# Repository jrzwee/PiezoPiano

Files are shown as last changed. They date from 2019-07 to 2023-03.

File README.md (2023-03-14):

# PiezoPiano
PiezoPiano is a PCB piano which can play one octave - all at once. It is programmed via Arduino. It is available for purchase in my [Tindie Store](https://www.tindie.com/products/zaan/piezo-piano/). 

If you like this project, feel free to support me 😇

 

<a href="https://www.buymeacoffee.com/zaan" target="_blank">Buy Me A Coffee</a>

<p align="center">
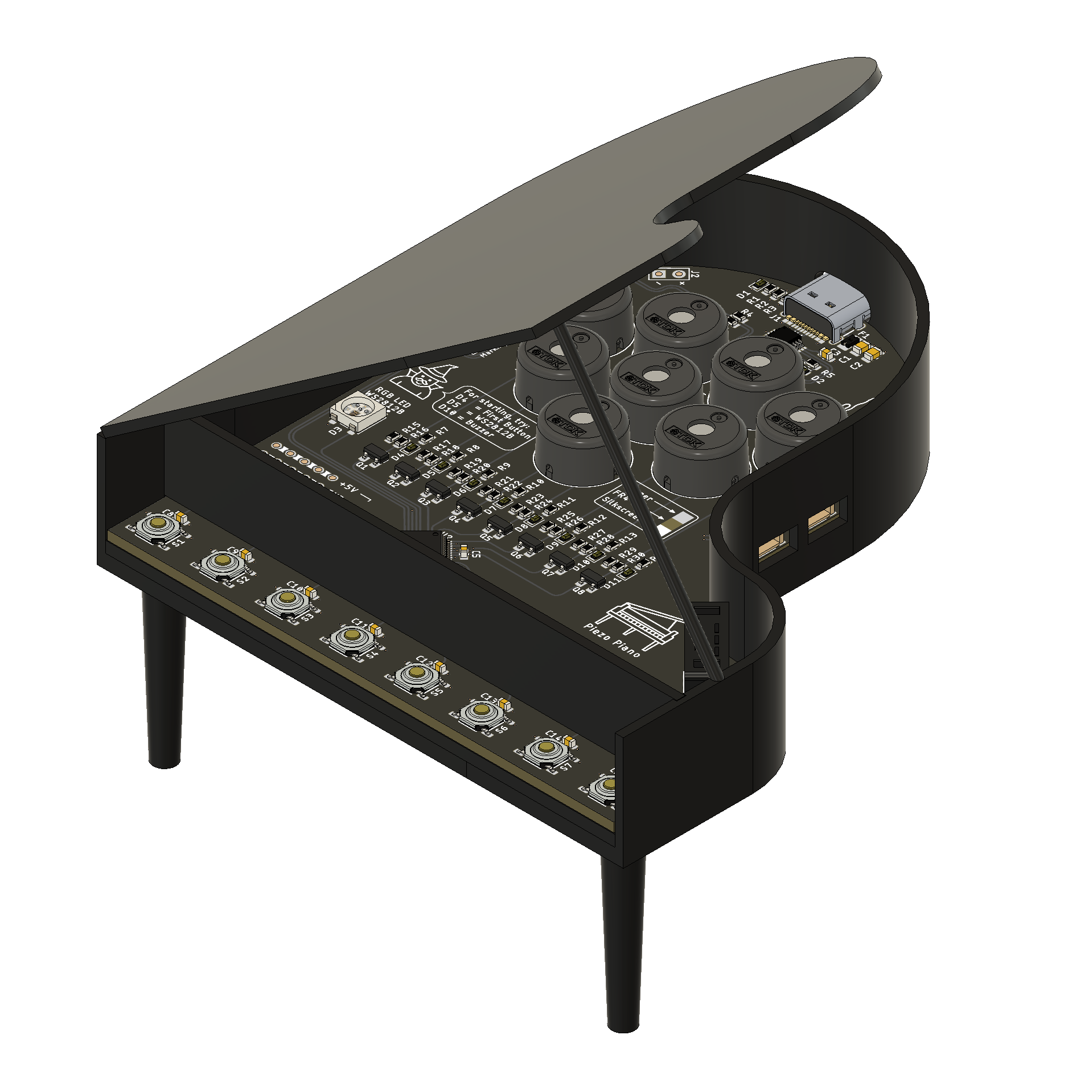
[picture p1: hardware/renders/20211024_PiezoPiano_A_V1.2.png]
  
</p>

## Setup for the Arduino IDE
This project is based on the great work of Hans with his [MegaCoreX](https://github.com/MCUdude/MegaCoreX). Visit this repo for further install instructions.
Select following settings in the Arduino IDE:

✅ **Board**: ATmega4809 \
✅ **COM Port**: Select the one your PiezoPiano is connected to \
✅ **Bootloader**: Optiboot (UART1 default pins) \
✅ **Pinout**: 48 pin standard

## Pinout
PCB Pinout

## Build of Material - BOM
TBD as there is a refactoring in the making.

## Renders
<p align="center">
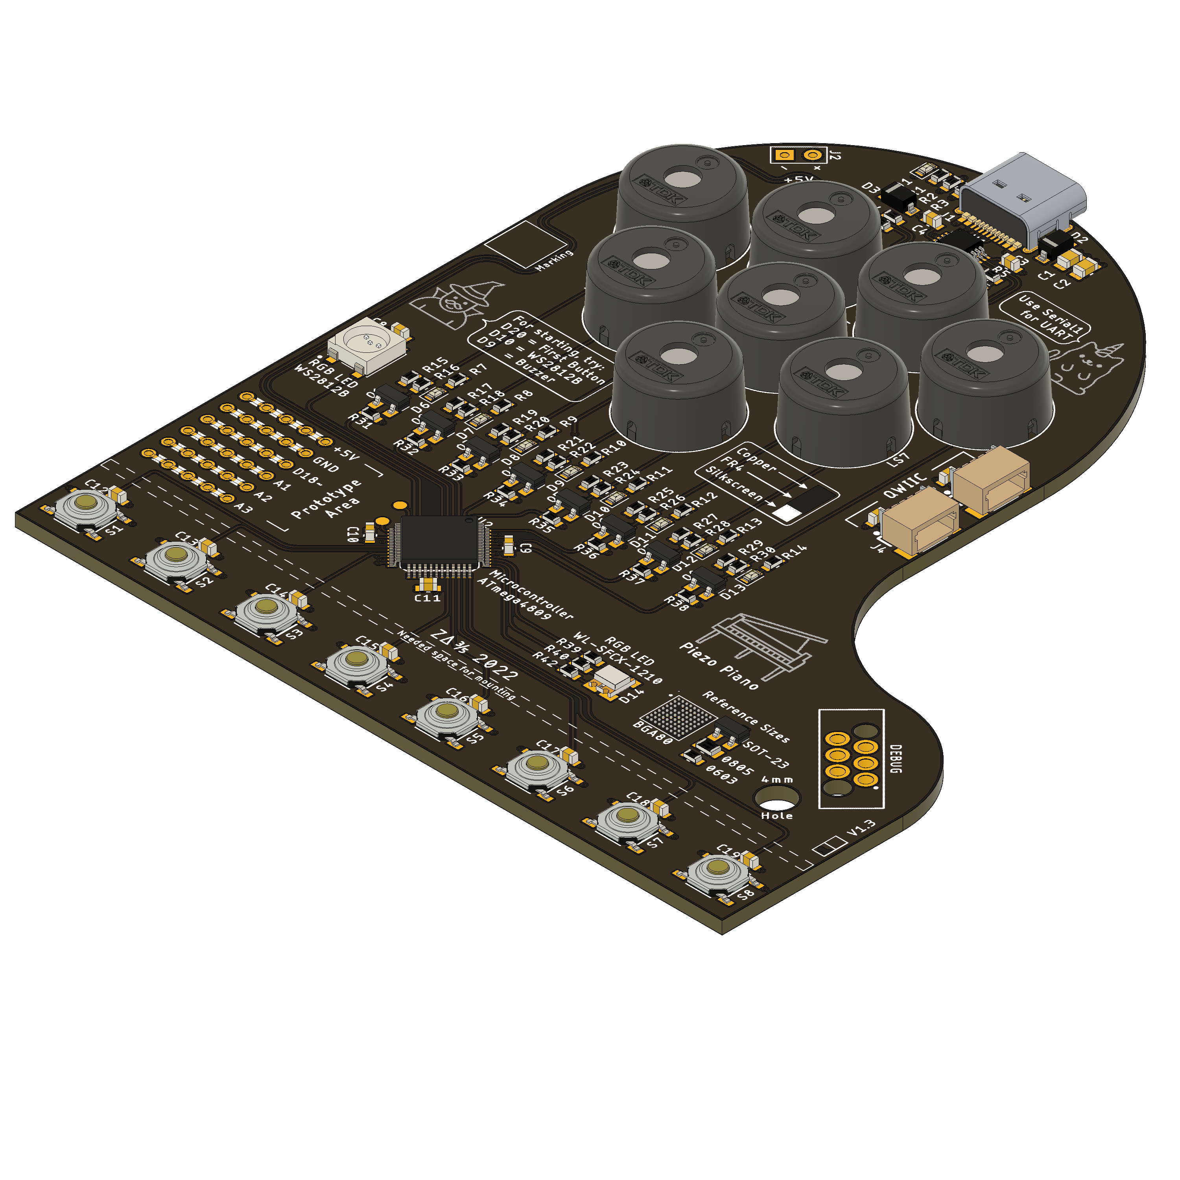
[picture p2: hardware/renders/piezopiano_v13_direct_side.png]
  
</p>

## License
[CERN-OHL-S](https://ohwr.org/cern_ohl_s_v2.pdf)

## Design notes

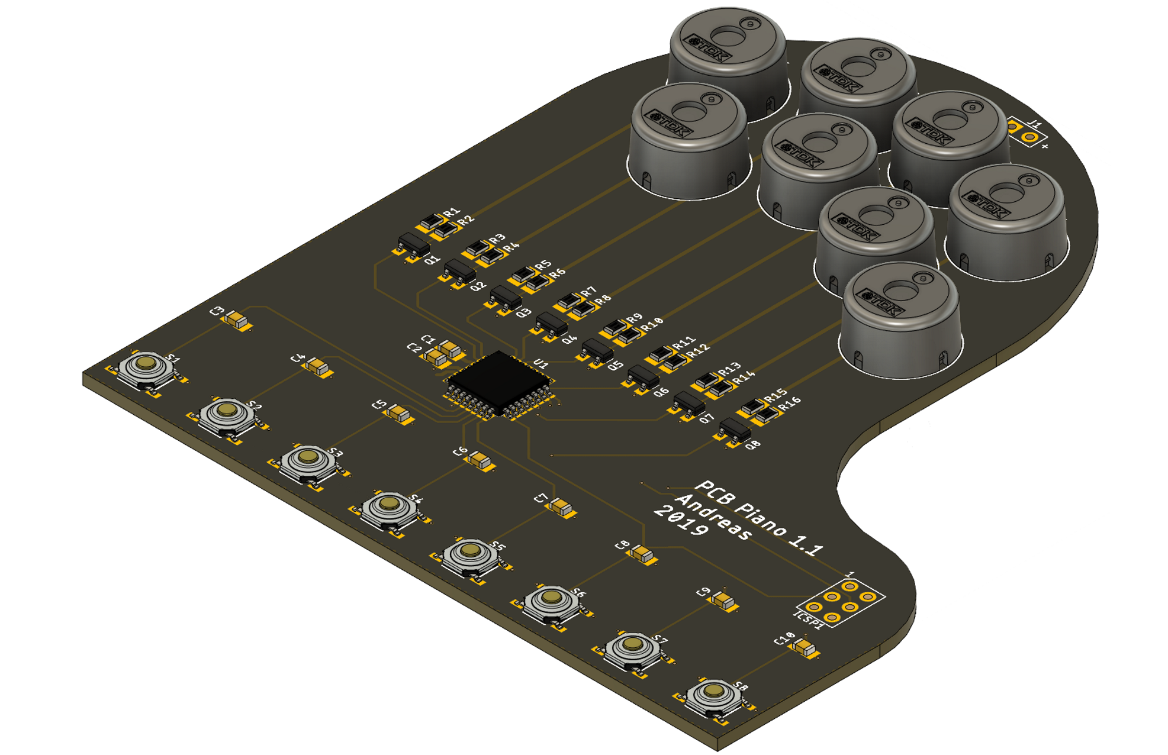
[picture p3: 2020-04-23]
hardware/renders/20200423_PiezoPiano_V1.1.png

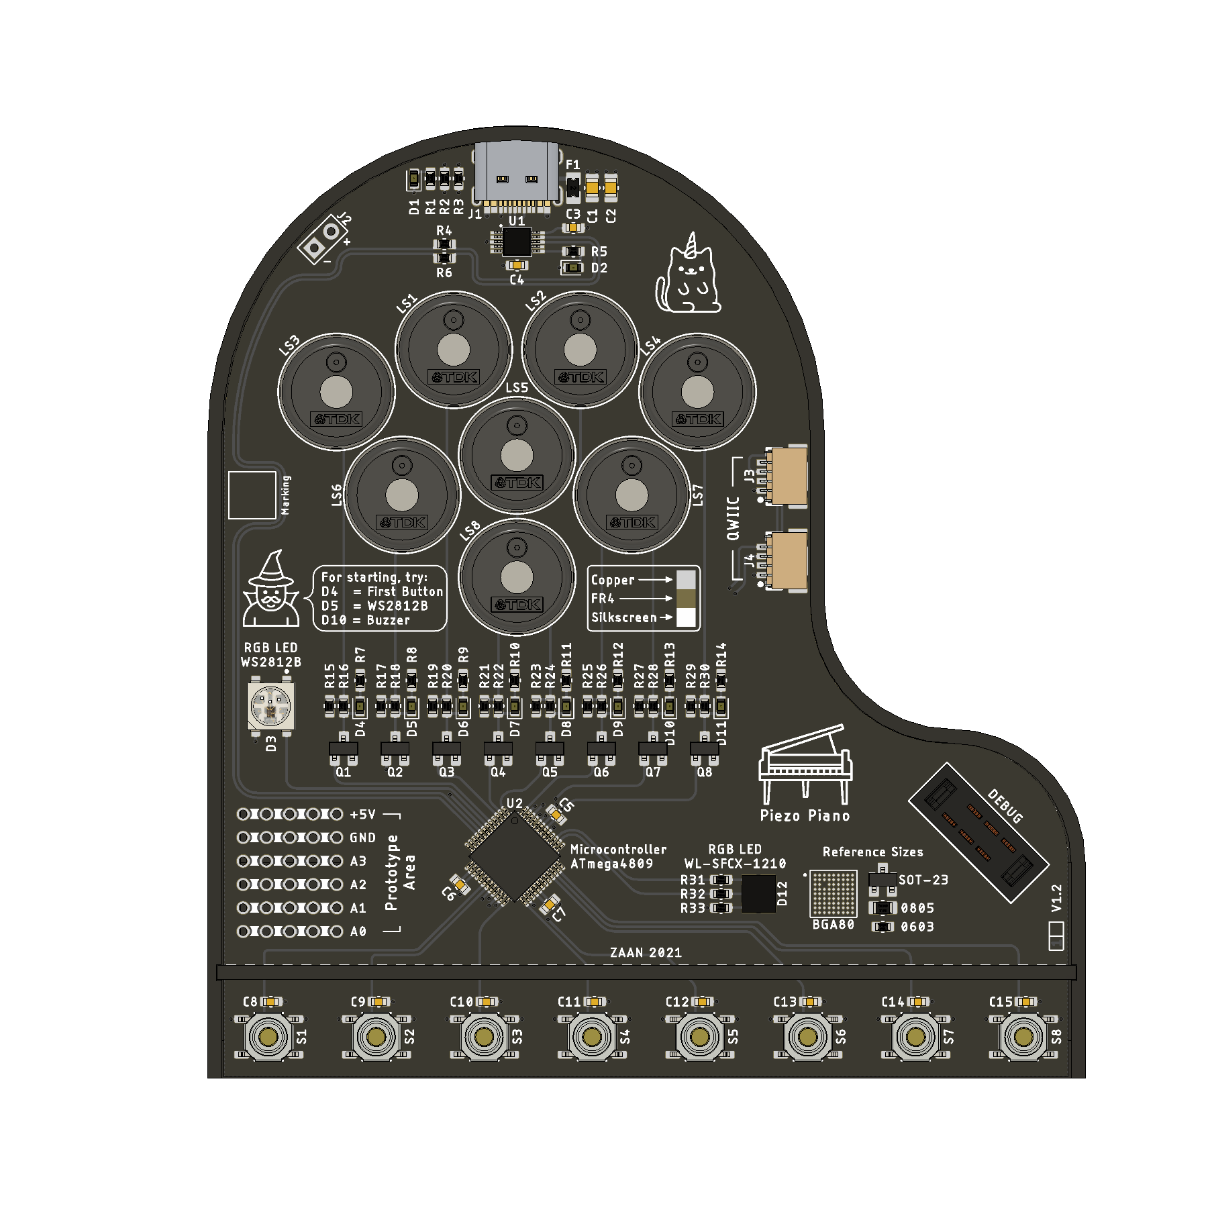
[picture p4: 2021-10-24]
hardware/renders/20211024_PiezoPiano_C_V1.2.png

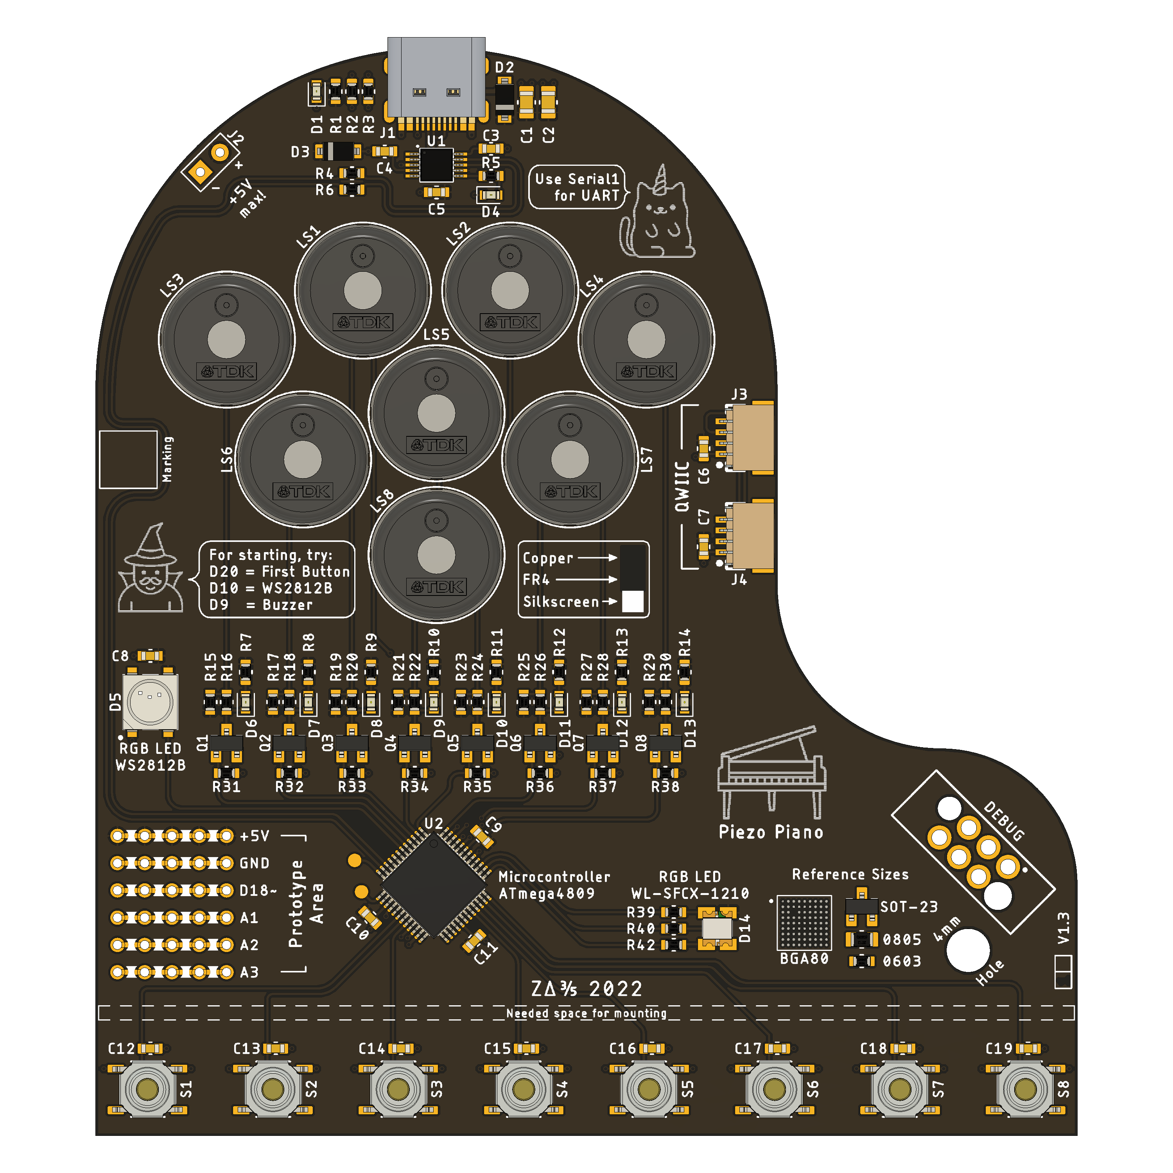
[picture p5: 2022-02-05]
hardware/renders/piezopiano_v13_direct.png

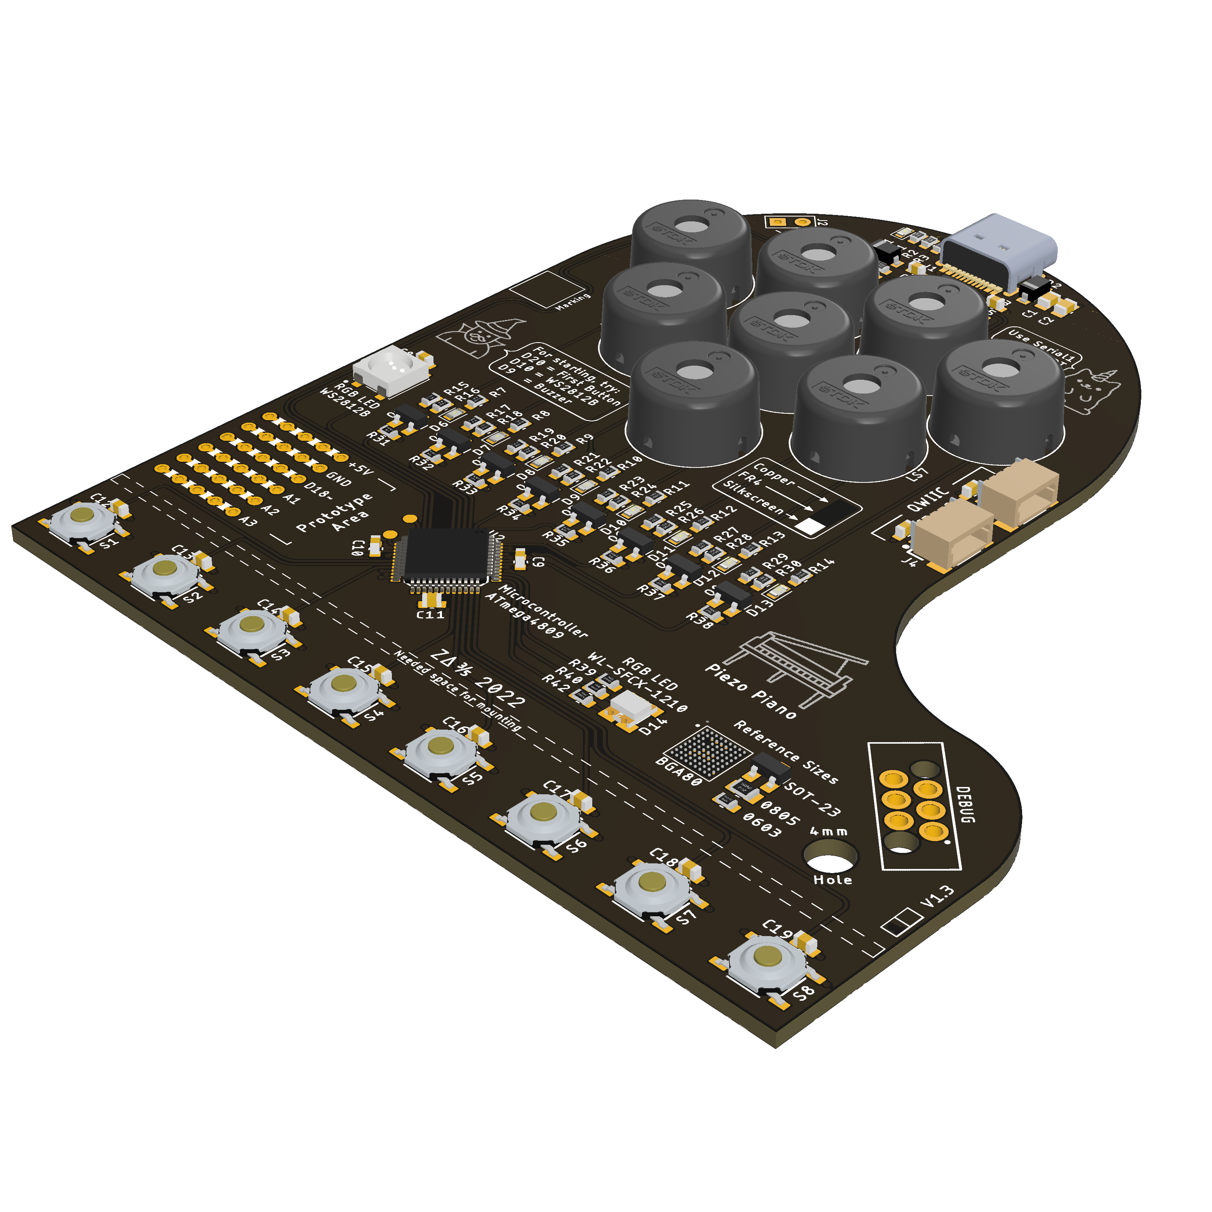
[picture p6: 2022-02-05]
hardware/renders/piezopiano_v13_render_side.png

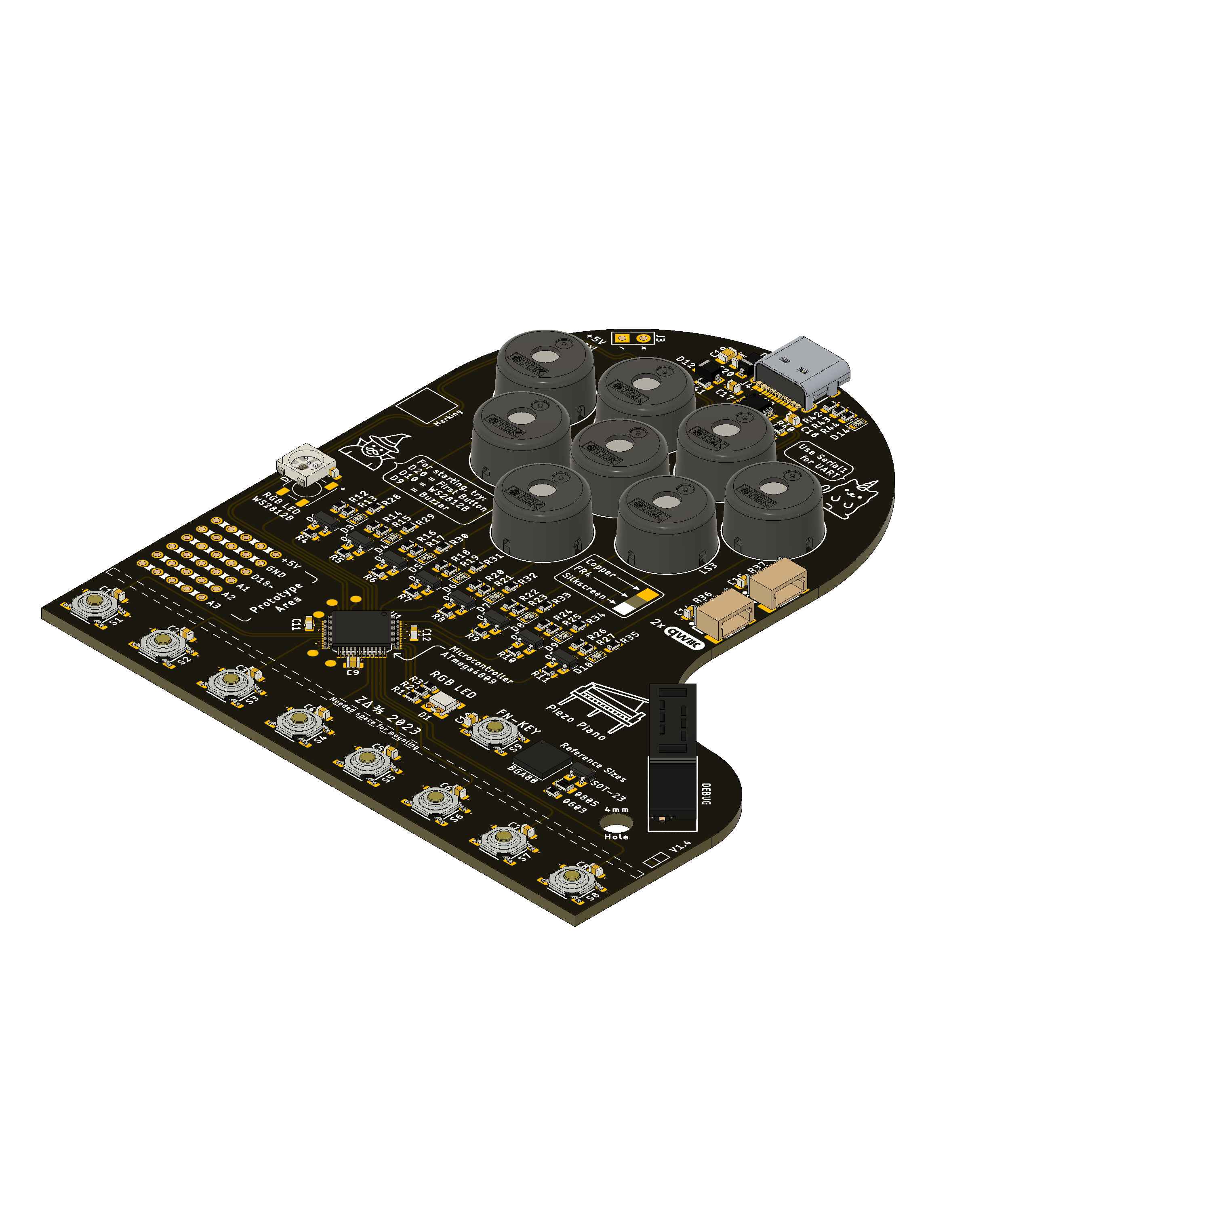
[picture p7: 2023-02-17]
hardware/renders/pp_v14_pcb_20220127.png

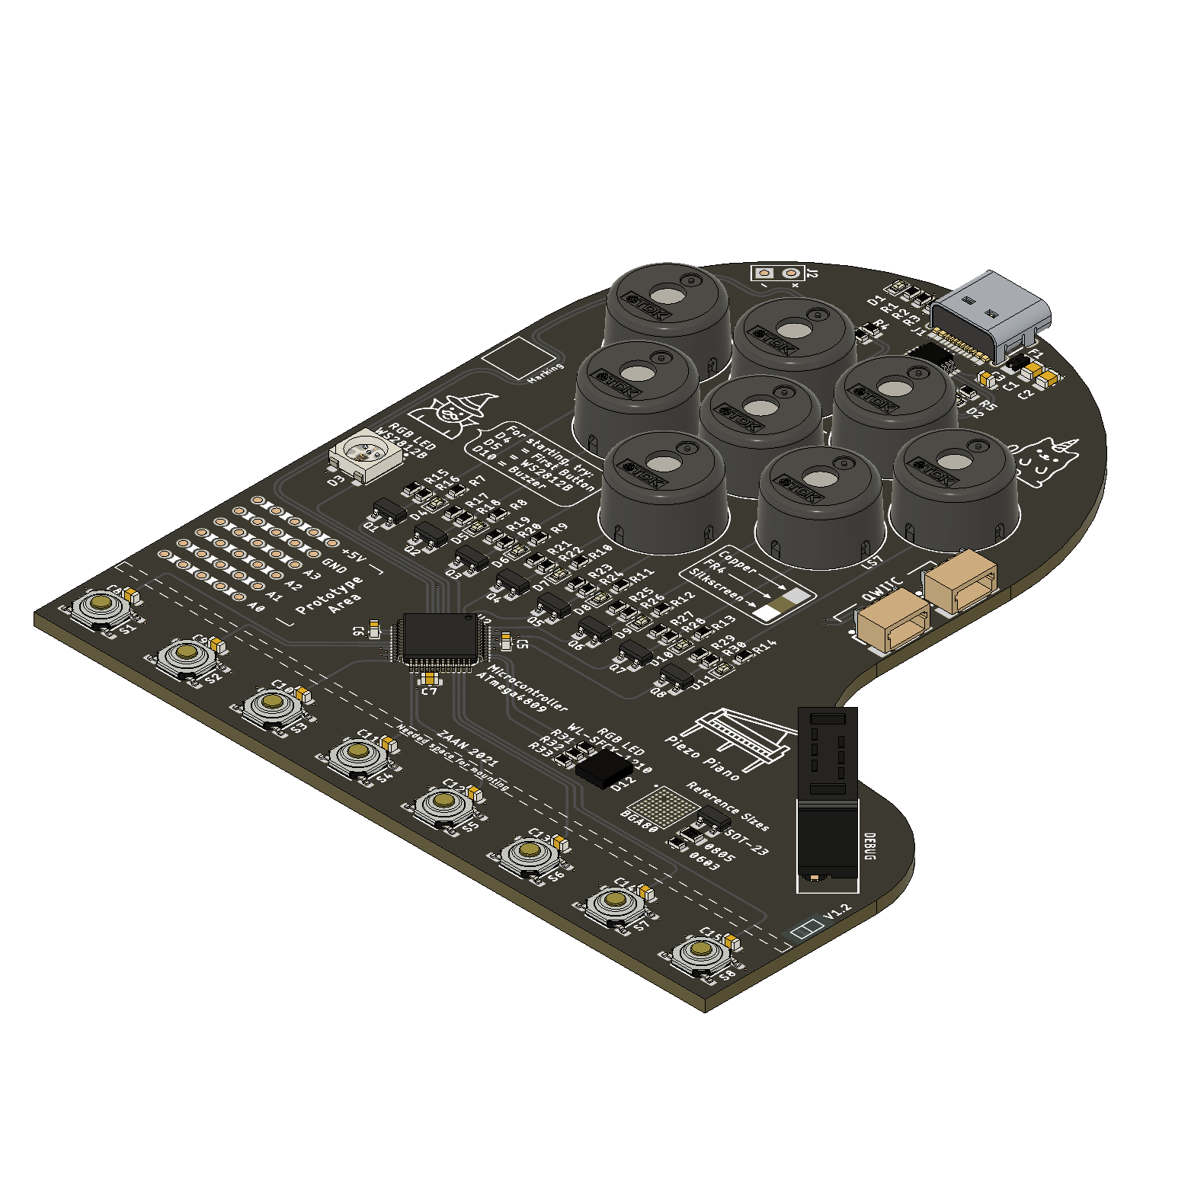
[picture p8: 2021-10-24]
hardware/renders/20211024_PiezoPiano_V1.2.png

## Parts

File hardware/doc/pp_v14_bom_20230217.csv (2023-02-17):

Qty | Value | Device | Package | Parts | Description | CATEGORY | COLOR | CREATED_BY | DATASHEET | DESCRIPTION | DIELECTRIC | DIGIKEY_PARTNO | DISTRIBUTOR-LINK | DISTRIBUTOR-PN | LCSC | MANUFACTURER | MF | MPN | OPERATING_TEMP | PACKAGE | PACKAGE-IN | PART_STATUS | POPULARITY | POWER | ROHS_COMPLIANT | SERIES | SUB-CATEGORY | SUB_CATEGORY | THERMALLOSS | TOLERANCE | TP_SIGNAL_NAME | TYPE | VALUE | VOLTAGE | VOLTAGE_FORWARD
1 |  | E6C1209RGBC3UDAM173000 | WL-SFCX_1210 | D1 | WL-SFCW SMD Full-color Chip LED Waterclear |  |  |  |  | RGB SMD LED |  |  |  |  | C375572 |  | EKINGLUX | E6C1209RGBC3UDA |  | 1210
2 |  | QWIIC_CONNECTORJS-1MM | 1X04_1MM_RA | J1, J2 | SMD Header 1MM 4Pin |  |  |  |  | Header SMD 1MM 4Pin |  |  |  |  | C145956 |  | BOOMELE | C145956
1 |  | USB_C2-LAYER | USB-C-16P | J4 | USB Type C 16 Pin Connector |  |  |  |  | USB Type C Female |  |  |  |  | C2927300 |  | YIYUAN | YTC-TC16S-23 |  | USB-C 16P
2 | 1.6k | 1.6KOHM-0603-1/10W-1% | R0603 | R1, R40 | 1.6kΩ resistor |  |  |  |  | Chip Resistor |  |  |  |  |  |  | Yageo | RC0603FR-071K6L |  | 1608 | 0603 |  |  | 0.1W |  |  |  |  |  | 1% |  |  | 1.6k | 75V
8 | 100R | 100OHM-0603-1/10W-1% | R0603 | R13, R15, R17, R19, R21, R23, R25, R27 | 100Ω resistor |  |  |  |  | Chip Resistor |  |  |  |  |  |  | Yageo | RC0603FR-07100RL |  | 1608 | 0603 |  |  | 0.1W |  |  |  |  |  | 1% |  |  | 100R | 75V
19 | 100n | 100NF-0603-50V-5% | C0603 | C1, C2, C3, C4, C5, C6, C7, C8, C9, C10, C11, C12, C13, C14, C15, C16, C17, C18, C20 | 100nF capacitor |  |  |  |  | Chip Capacitor | X7R |  |  |  |  |  | Yageo | CC0603JRX7R9BB104 |  | 1606 | 0603 |  |  |  |  |  |  |  |  | 5% |  |  | 100n | 50V
17 | 10k | 10KOHM-0603-1/10W-1% | R0603 | R4, R5, R6, R7, R8, R9, R10, R11, R12, R14, R16, R18, R20, R22, R24, R26, R41 | 10kΩ resistor |  |  |  |  | Chip Resistor |  |  |  |  |  |  | Yageo | RC0603FR-0710KL |  | 1608 | 0603 |  |  | 0.1W |  |  |  |  |  | 1% |  |  | 10k | 75V
11 | 1k | 1KOHM-0603-1/10W-1% | R0603 | R2, R28, R29, R30, R31, R32, R33, R34, R35, R38, R39 | 1kΩ resistor |  |  |  |  | Chip Resistor |  |  |  |  |  |  | Yageo | RC0603FR-071KL |  | 1608 | 0603 |  |  | 0.1W |  |  |  |  |  | 1% |  |  | 1k | 75V
2 | 2.2k | 2.2KOHM-0603-1/10W-1% | R0603 | R3, R44 | 2.2kΩ resistor |  |  |  |  | Chip Resistor |  |  |  |  |  |  | Yageo | RC0603FR-072K2L |  | 1608 | 0603 |  |  | 0.1W |  |  |  |  |  | 1% |  |  | 2.2k | 75V
1 | 22u | 22UF-0805-25V-20% | C0805 | C19 | 22uF capacitor |  |  |  |  | Chip Capacitor | X5R |  |  |  |  |  | Murata | GRM21BR61E226ME44L |  | 2012 | 0805 |  |  |  |  |  |  |  |  | 20% |  |  | 22u | 25V
2 | 4.7k | 4.7KOHM-0603-1/10W-1% | R0603 | R36, R37 | 4.7kΩ resistor |  |  |  |  | Chip Resistor |  |  |  |  |  |  | Yageo | RC0603FR-074K7L |  | 1608 | 0603 |  |  | 0.1W |  |  |  |  |  | 1% |  |  | 4.7k | 75V
2 | 5.1k | 5.1KOHM-0603-1/10W-1% | R0603 | R42, R43 | 5.1kΩ resistor |  |  |  |  | Chip Resistor |  |  |  |  |  |  | Yageo | RC0603FR-075K1L |  | 1608 | 0603 |  |  | 0.1W |  |  |  |  |  | 1% |  |  | 5.1k | 75V
8 | AO3400A | AO3400A | SOT23 | Q1, Q2, Q3, Q4, Q5, Q6, Q7, Q8 | N-CHANNEL MOS FET |  |  |  |  | N-CHANNEL MOSFET |  |  |  |  | C20917 |  | Alpha & Omega Semicon | AO3400A |  | SOT-23
1 | ATMEGA4809 | ATMEGA4809 | TQFP48 | U1 | ATMEGA4809 |  |  |  | http://ww1.microchip.com/downloads/en/DeviceDoc/40002016A.pdf | ATmega4809 Microcontroller |  |  | https://www.digikey.com/product-detail/en/microchip-technology/ATMEGA4809-AFR/ATMEGA4809-AFRCT-ND/8540756 | ATMEGA4809-AFRCT-ND | C189475 | Microchip |  | ATMEGA4809-AFR
2 | B5819WSL | B5819WSL | SOD123 | D12, D13 | Schottky Diode |  |  |  |  | Schottky Diode |  |  |  |  | C8598 |  | Changjiang Electronics Tech (CJ) | B5819W SL |  | SOD-123 |  |  |  |  |  |  |  |  |  |  |  |  |  |  | 600mV
1 | CH340E_MSOP10 | CH340E_MSOP10 | MSOP10 | U2 | CH340EUSB to serial chipFootprint: MSOP-10 Source: Datasheet Manufacturer: Jiangsu Qin Heng |  |  |  |  | UART Converter |  |  |  |  | C99652 |  | Jiangsu Qin Heng | CH340E |  | MSOP-10
1 | CON2 | CON2 | H2-2.54 | J3
1 | DNP | AVR-UPDI-6-SKEDD | 490107670612_DEBUGGING | DEBUG |  |  |  |  |  |  |  |  |  |  |  |  |  |  |  |  |  |  |  |  |  |  |  |  |  |  |  |  | DNP
1 | DNP | DMN3404L | SOT23 | REFX4 | N-CHANNEL MOS FET |  |  |  |  | N-CHANNEL MOSFET |  |  |  |  |  |  | Diodes Incorporated | DMN3404L-7 |  | SOT-23
1 | DNP | DNP-0603 | R0603 | REFX1 |  |  |  |  |  | Chip Resistor |  |  |  |  |  |  |  |  |  |  |  |  |  |  |  |  |  |  |  |  |  |  | DNP
1 | DNP | DNP-0805 | R0805 | REFX2 |  |  |  |  |  | Chip Resistor |  |  |  |  |  |  |  |  |  |  |  |  |  |  |  |  |  |  |  |  |  |  | DNP
1 | DNP | MSP432P401RIZXHR | BGA80 | REFX3 | IC MCU 32BIT 256KB FLASH 80NFBGA |  |  | PCBLayout.com |  |  |  | 296-45566-6-ND |  |  |  | Texas Instruments |  | MSP432P401RIZXHR |  | 80-NFBGA
6 | DNP | PINROW-1X5 | 1X01 | JP1, JP2, JP3, JP4, JP5, JP6 | PIN HEADER | CONNECTOR |  |  |  |  |  |  |  |  |  |  |  |  |  |  |  |  |  |  |  |  | PIN-HEADER |  |  |  |  |  | DNP
8 | F/CM12P | F/CM12P | CM12P/5.0P | LS1, LS2, LS3, LS4, LS5, LS6, LS7, LS8 | BUZZER |  |  |  |  | Piezo Buzzer |  |  |  |  | C219727 |  | ZLFY | ZL-YDW1207-4005PA-5.0
1 | LED_BLUE | CHIP-FLAT-B_0603-0.55MM | LEDC1608X55N_FLAT | D11 |  | LED | BLUE |  |  | CHIP LED FLAT |  |  |  |  | C72043 | Everlight Elec |  | 19-217/GHC-YR1S2/3T |  |  |  |  |  |  |  |  | CHIP |  |  |  |  | FLAT_TOP | LED_BLUE
1 | LED_EMERALD | CHIP-FLAT-G_0603-0.55MM | LEDC1608X55N_FLAT | D14 |  | LED | EMERALD |  |  | CHIP LED FLAT |  |  |  |  | C72041 | Everlight Elec |  | 19-217/BHC-ZL1M2RY/3T |  |  |  |  |  |  |  |  | CHIP |  |  |  |  | FLAT_TOP | LED_EMERALD
8 | LED_YELLOW | CHIP-FLAT-Y_0603-0.55MM | LEDC1608X55N_FLAT | D3, D4, D5, D6, D7, D8, D9, D10 |  | LED | YELLOW |  |  | CHIP LED FLAT |  |  |  |  | C72038 | Everlight Elec |  | 19-213/Y2C-CQ2R2L/3T(CY) |  |  |  |  |  |  |  |  | CHIP |  |  |  |  | FLAT_TOP | LED_YELLOW
5 | PTR1B1,27 | PTR1B1,27 | B1,27 | TP1, TP2, TP3, TP4, TP5 | TEST PIN |  |  |  |  |  |  |  |  |  |  |  |  |  |  |  |  |  | 2
9 | TS-1187A-B-A-B | TS-1187A-B-A-B | TACTILE_SWITCH_SMD_5.2MM | S1, S2, S3, S4, S5, S6, S7, S8, S9 |  |  |  |  |  | Tactile Button SMD |  |  |  |  | C318884 |  | XKB Connectivity | TS-1187A-B-A-B
1 | WS2812B | WS2812B | WS2812B | D2 | Intelligent control LED integrated light source | LED | RGB |  |  | WS2812 RGB LED |  |  |  |  | C2761795 | Worldsemi |  | WS2812B-B/W | -25 ℃ to +80℃(TJ) |  |  | Active |  |  |  |  |  | RGB

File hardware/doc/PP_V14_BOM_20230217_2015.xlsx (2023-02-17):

Model | PP
Version | V1.4
BOM Revision | A
Initials | AZ
Date | 2023-02-17
Description | Qty | Parts | Value | MPN | MF | Info
Chip Capacitor | 19 | C1, C2, C3, C4, C5, C6, C7, C8, C9, C10, C11, C12, C13, C14, C15, C16, C17, C18, C20 | 100n 0603 50V X7R 5% | CC0603JRX7R9BB104 | Yageo
Chip Resistor | 17 | R4, R5, R6, R7, R8, R9, R10, R11, R12, R14, R16, R18, R20, R22, R24, R26, R41 | 10k 0603 75V 1% | RC0603FR-0710KL | Yageo
Chip Resistor | 11 | R2, R28, R29, R30, R31, R32, R33, R34, R35, R38, R39 | 1k 0603 75V 1% | RC0603FR-071KL | Yageo
Tactile Button SMD | 9 | S1, S2, S3, S4, S5, S6, S7, S8, S9 |  | TS-1187A-B-A-B | XKB Connectivity
Chip Resistor | 8 | R13, R15, R17, R19, R21, R23, R25, R27 | 100R 0603 75V 1% | RC0603FR-07100RL | Yageo
N-CHANNEL MOSFET | 8 | Q1, Q2, Q3, Q4, Q5, Q6, Q7, Q8 | SOT-23 | AO3400A | Alpha & Omega Semicon
Piezo Buzzer | 8 | LS1, LS2, LS3, LS4, LS5, LS6, LS7, LS8 |  | ZL-YDW1207-4005PA-5.0 | ZLFY
CHIP LED FLAT | 8 | D3, D4, D5, D6, D7, D8, D9, D10 | LED_YELLOW | 19-213/Y2C-CQ2R2L/3T(CY) | Everlight Elec
Header SMD 1MM 4Pin | 2 | J1, J2 |  | C145956 | BOOMELE
Chip Resistor | 2 | R1, R40 | 1.6k 0603 75V 1% | RC0603FR-071K6L | Yageo
Chip Resistor | 2 | R36, R37 | 4.7k 0603 75V 1% | RC0603FR-074K7L | Yageo
Chip Resistor | 2 | R42, R43 | 5.1k 0603 75V 1% | RC0603FR-075K1L | Yageo
Schottky Diode | 2 | D12, D13 | SOD-123 | B5819W SL | Changjiang Electronics Tech (CJ)
RGB SMD LED | 1 | D1 | 1210 | E6C1209RGBC3UDA | EKINGLUX
USB Type C Female | 1 | J4 | USB-C 16P | YTC-TC16S-23 | YIYUAN
Chip Resistor | 1 | R3, R44 | 2.2k 0603 75V 1% | RC0603FR-072K2L | Yageo
Chip Capacitor | 1 | C19 | 22u 0805 25V X5R 20% | GRM21BR61E226ME44L | Murata
ATmega4809 Microcontroller | 1 | U1 |  | ATMEGA4809-AFR | Microchip
UART Converter | 1 | U2 | MSOP-10 | CH340E | Jiangsu Qin Heng
CHIP LED FLAT | 1 | D11 | LED_BLUE | 19-217/GHC-YR1S2/3T | Everlight Elec
CHIP LED FLAT | 1 | D14 | LED_EMERALD | 19-217/BHC-ZL1M2RY/3T | Everlight Elec
WS2812 RGB LED | 1 | D2 |  | WS2812B-B/W | WORLDSEMI

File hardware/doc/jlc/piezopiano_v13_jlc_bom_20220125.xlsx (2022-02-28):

Comment | Designator | Footprint | JLCPCB Part
100n 0603 50V X7R 5% | C3, C4, C5, C6, C7, C8, C9, C10, C11, C12, C13, C14, C15, C16, C17, C18, C19 | C0603 | C14663
10k 0603 75V 1% | R15, R17, R19, R21, R23, R25, R27, R29, R31, R32, R33, R34, R35, R36, R37, R38 | R0603 | C25804
1k 0603 75V 1% | R1, R4, R5, R6, R7, R8, R9, R10, R11, R12, R13, R14, R39, R40, R42 | R0603 | C21190
LED_YELLOW | D1, D4, D6, D7, D8, D9, D10, D11, D12, D13 | D0603 | C72038
100R 0603 75V 1% | R16, R18, R20, R22, R24, R26, R28, R30 | R0603 | C22775
SOT-23 | Q1, Q2, Q3, Q4, Q5, Q6, Q7, Q8 | SOT-23 | C20917
Piezo Buzzer | LS1, LS2, LS3, LS4, LS5, LS6, LS7, LS8 |  | C219727
Tactile Button | S1, S2, S3, S4, S5, S6, S7, S8 |  | C318884
SMT Connector | J3, J4 |  | C145956
22u 0805 25V X5R 20% | C1, C2 | C0805 | C45783
5.1k 0603 75V 1% | R2, R3 | R0603 | C23186
SOD-123 Schottky | D2, D3 | SOD-123 | C8598
RGB | D14 | 1210
USB-C 16P | J1 |  | C167321
ATMEGA4809-AFR | U2 |  | C189475
MSOP-10 CH340 | U1 |  | C99652
WS2812 | D5 |  | C2761795

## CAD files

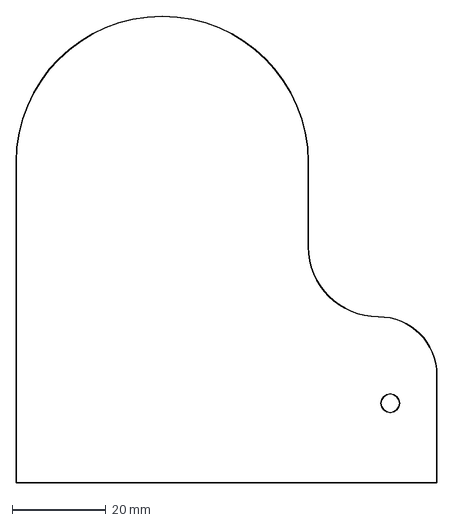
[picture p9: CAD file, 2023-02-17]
hardware/cad/DXF/pp-pcb-basis-20230125.dxf
90.0 x 99.8 mm

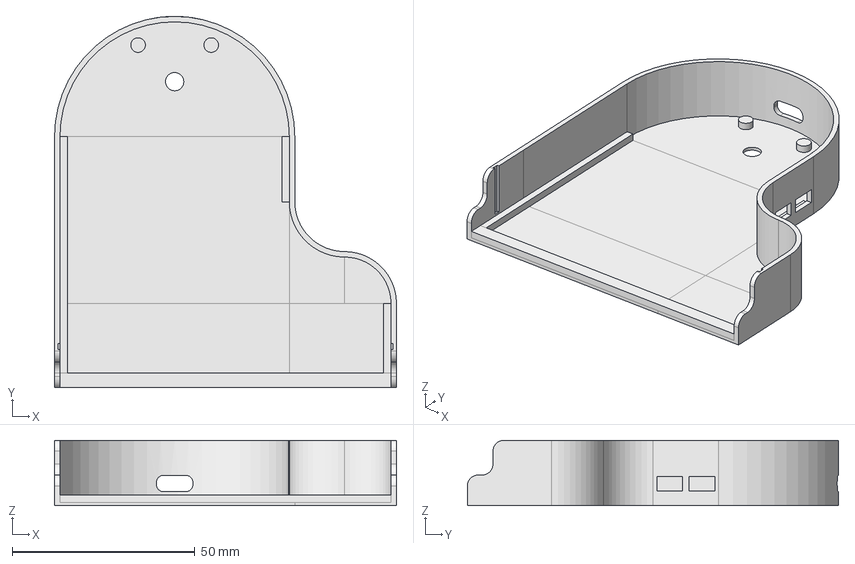
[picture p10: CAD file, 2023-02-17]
hardware/cad/pp_basis_20230125.FCStd
93.5 x 101.5 x 17.9 mm

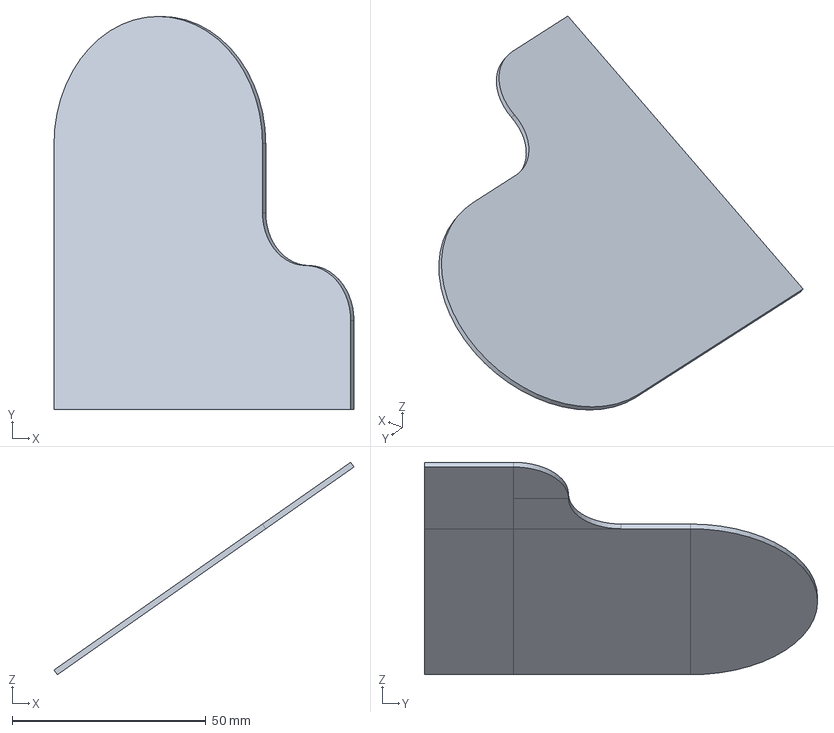
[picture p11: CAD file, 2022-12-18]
hardware/cad/pp_abdeckung_20220407.step
77.5 x 101.5 x 54.9 mm

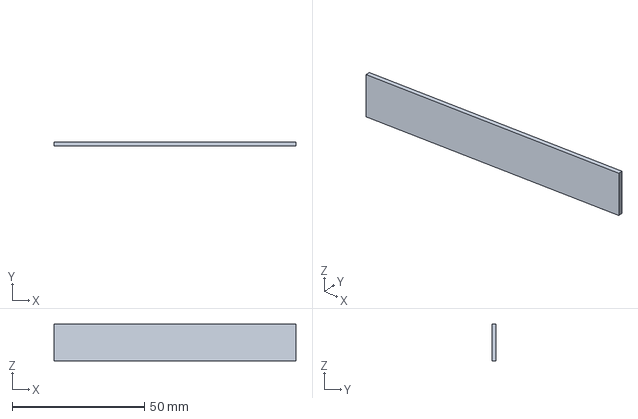
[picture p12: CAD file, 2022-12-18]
hardware/cad/pp_vorderplatte_20220407.step
91.5 x 1.50 x 13.9 mm

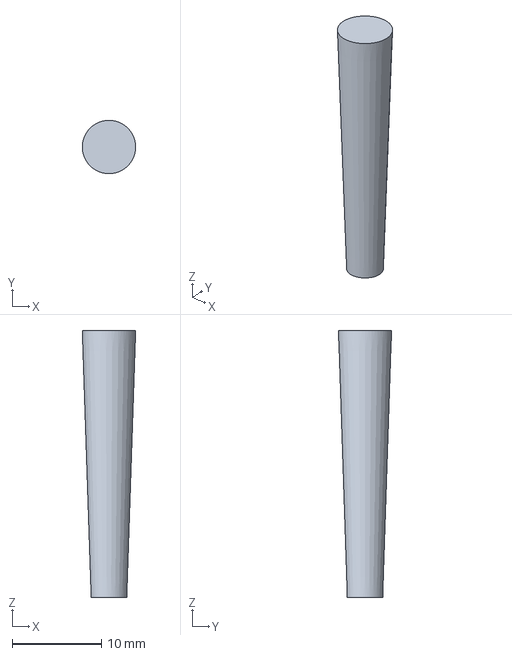
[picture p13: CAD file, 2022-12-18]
hardware/cad/pp_bein_20220407.step
5.99 x 6.00 x 30.0 mm

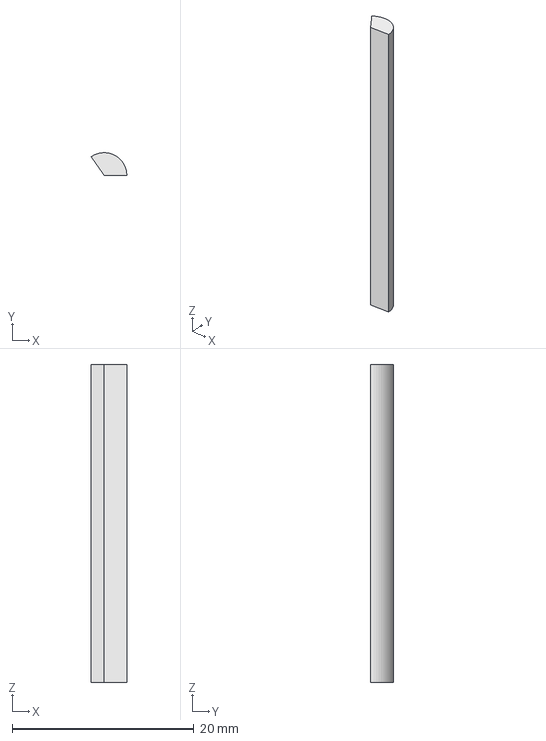
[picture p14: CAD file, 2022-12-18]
hardware/cad/pp_winkel_20220407.step
3.93 x 2.50 x 35.0 mm

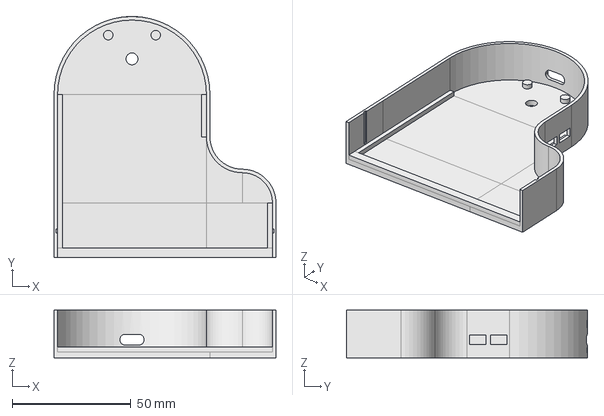
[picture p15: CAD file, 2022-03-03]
hardware/cad/pp_basis_20220303.step
93.5 x 101.5 x 20.1 mm

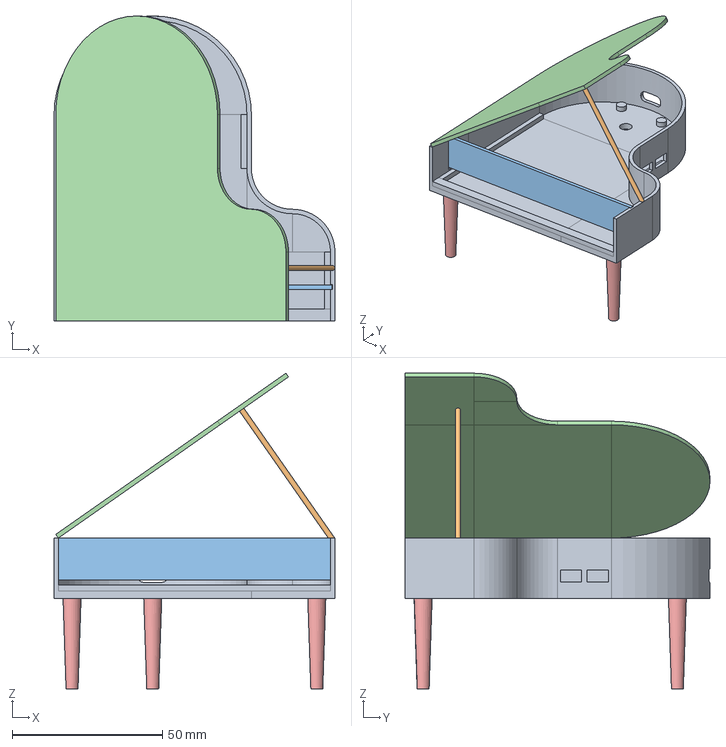
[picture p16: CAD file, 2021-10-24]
hardware/cad/pp_cutouts_20211024.step
93.5 x 101.5 x 105.0 mm

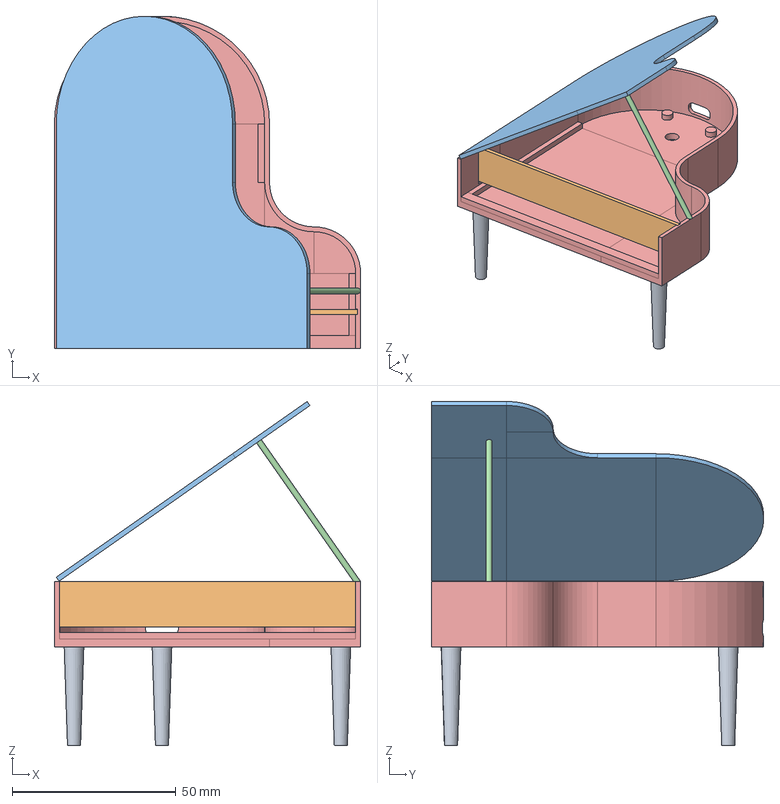
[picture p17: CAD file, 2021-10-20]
hardware/cad/pp_cutout_20211020.step
93.5 x 101.5 x 105.0 mm
Bein_1 x 2
Bein_2 x 2
Bein_3 x 2
Platte_Vorne
Abdeckung
Ständer
Basis

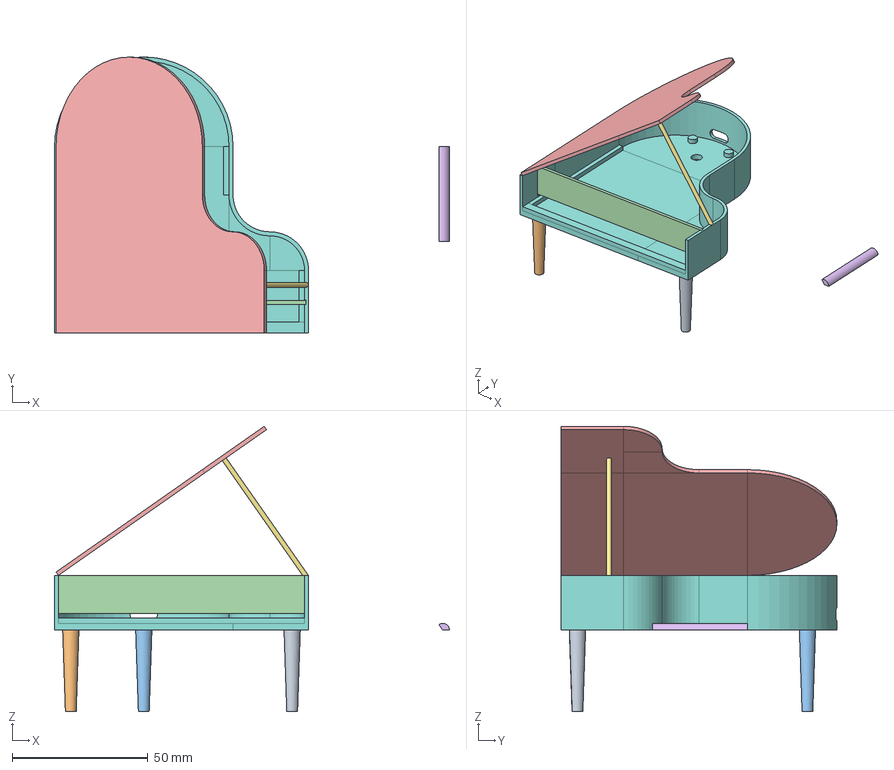
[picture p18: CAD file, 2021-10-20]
hardware/cad/2019.07.02 21.37 - PiezoPiano.FCStd
145.3 x 101.5 x 105.0 mm
Bein_1
Bein_2
Bein_3
Platte_Vorne
Abdeckung
Winkel
Ständer
Basis

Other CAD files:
hardware/cad/pp_20200707.step

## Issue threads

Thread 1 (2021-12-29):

Replace fuse with diode

jrzwee, 2021-12-29:
Replace the fuse with a Schottky diode e.g. PMEG6020

jrzwee, 2022-02-16:
This was done in version V1.3

Closed 2022-02-16.

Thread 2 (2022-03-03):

Random LED on first connection

jrzwee, 2022-03-03:
For the current version if the Piezo Piano gets connected via USB one of the right side leds shines.

Maybe the configuration of the interrupts or gpio is buggy.

jrzwee, 2022-04-06:
Capacitor for buttons is discharged at start and then pulled up with internal pullup of the microcontroller. This takes a bit of time and therefore the buttons are recognised as pressed.
The fix was to put the timer init a bit later in code.

Closed 2022-04-06.

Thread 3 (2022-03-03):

"tone()" vs timer generation

jrzwee, 2022-03-03:
The generation of a note reults in different soundings.

tone(xxx, NOTE_C4) sounds different then generated by pin toggle in the ISR.

-> Adapt the generation to correspond with tone function.

jrzwee, 2022-04-06:
F_TIMER has to be set to 65536/2 for this algorithm

Closed 2022-04-06.

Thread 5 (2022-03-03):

VIN header safety diode

jrzwee, 2022-03-03:
Run the vin header through the diode for safety.

-> Change placement besides USB-C connector. Diode to the left, LED to the right.

jrzwee, 2022-12-18:
Implemented with V1.4

Closed 2022-12-18.

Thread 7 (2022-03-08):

Missing I2C Pullups

jrzwee, 2022-03-08:
For the QWIIC connector systems are (optional) pullups needed.

jrzwee, 2022-12-18:
Added with V1.4

Closed 2022-12-18.

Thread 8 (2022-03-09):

Rework RTS / CTS pin config

jrzwee, 2022-03-09:
Maybe add a DNP pullup?

jrzwee, 2022-12-18:
Pullup added on V1.4

Closed 2022-12-18.

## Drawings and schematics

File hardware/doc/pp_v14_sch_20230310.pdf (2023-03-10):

# SOT-23 AO3400A

# SOT-23 AO3400A

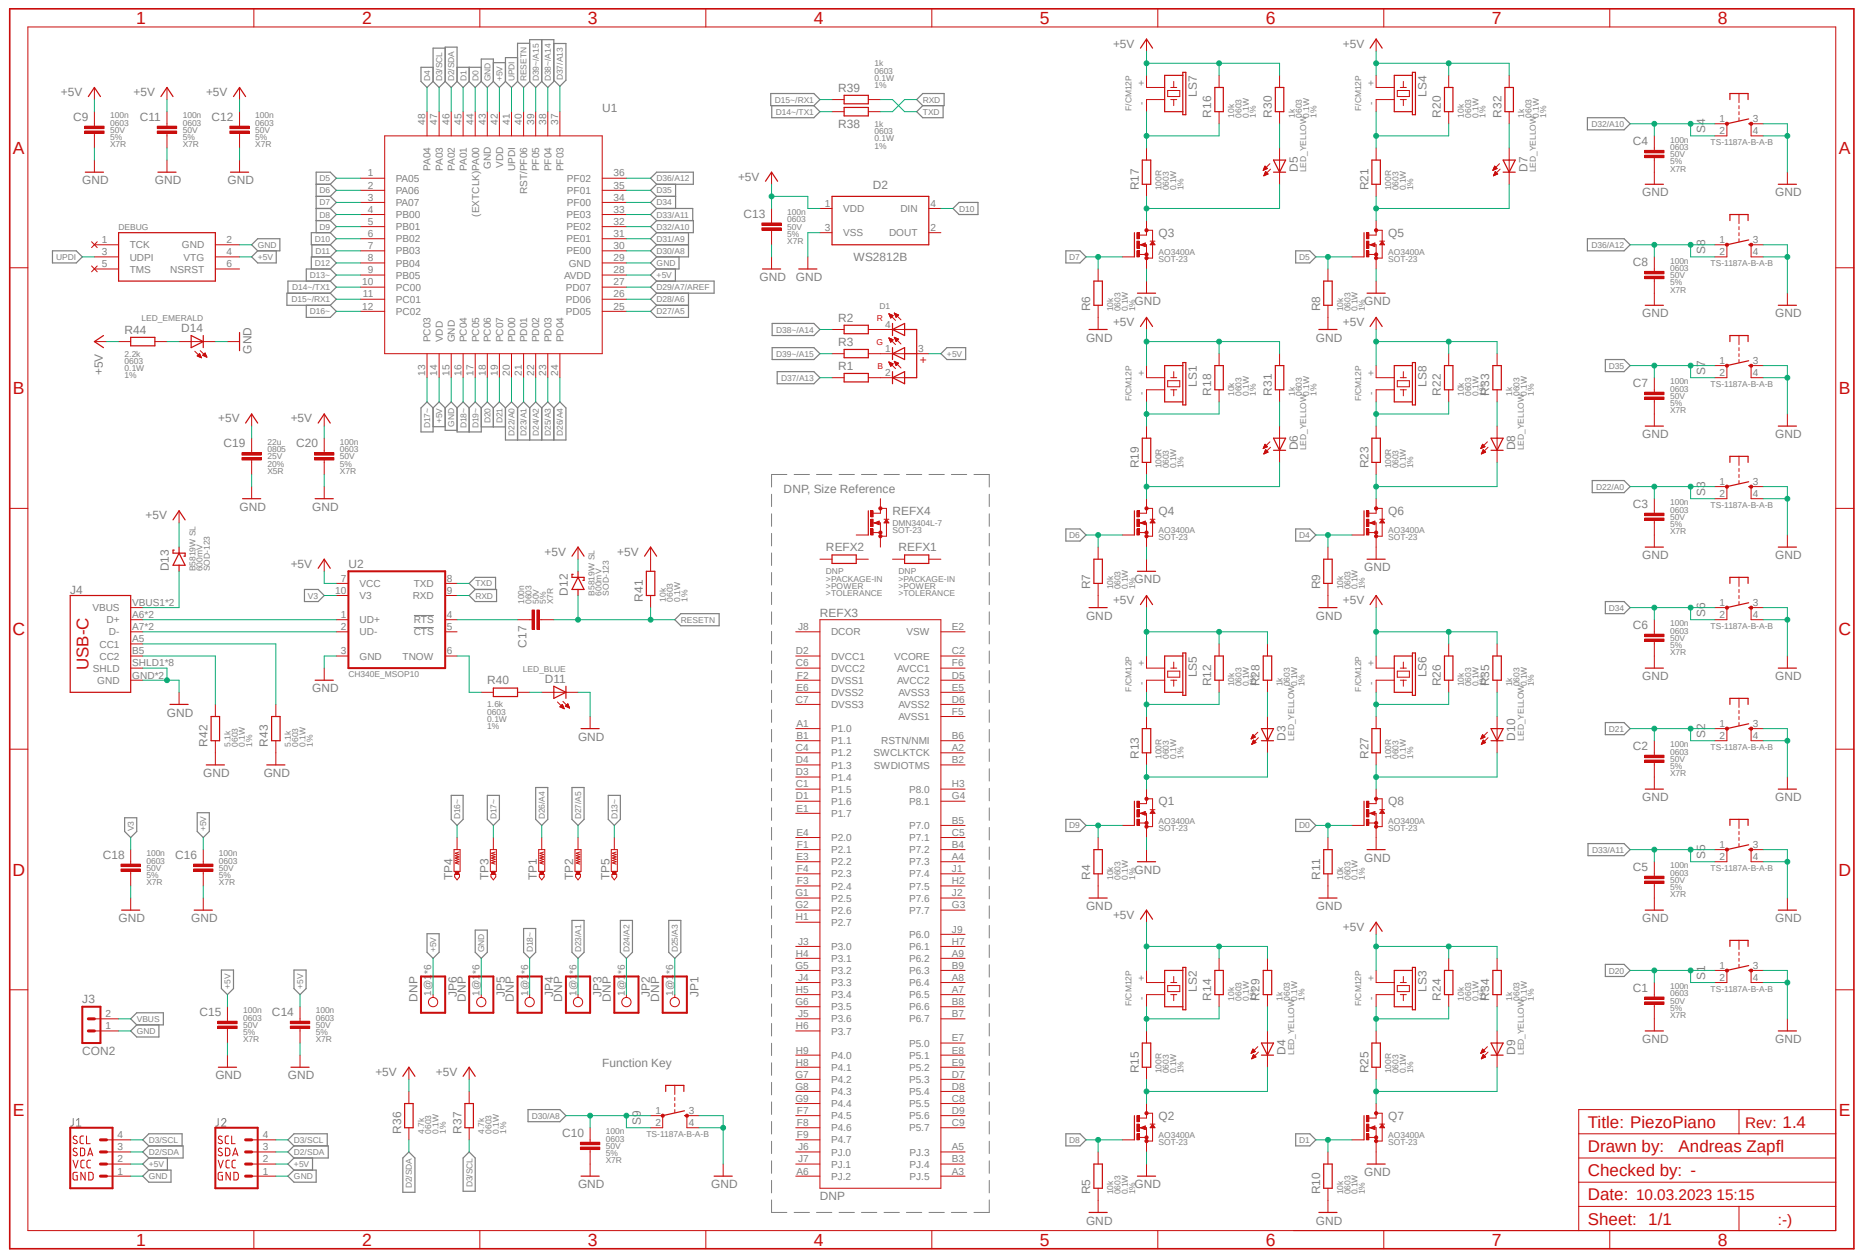
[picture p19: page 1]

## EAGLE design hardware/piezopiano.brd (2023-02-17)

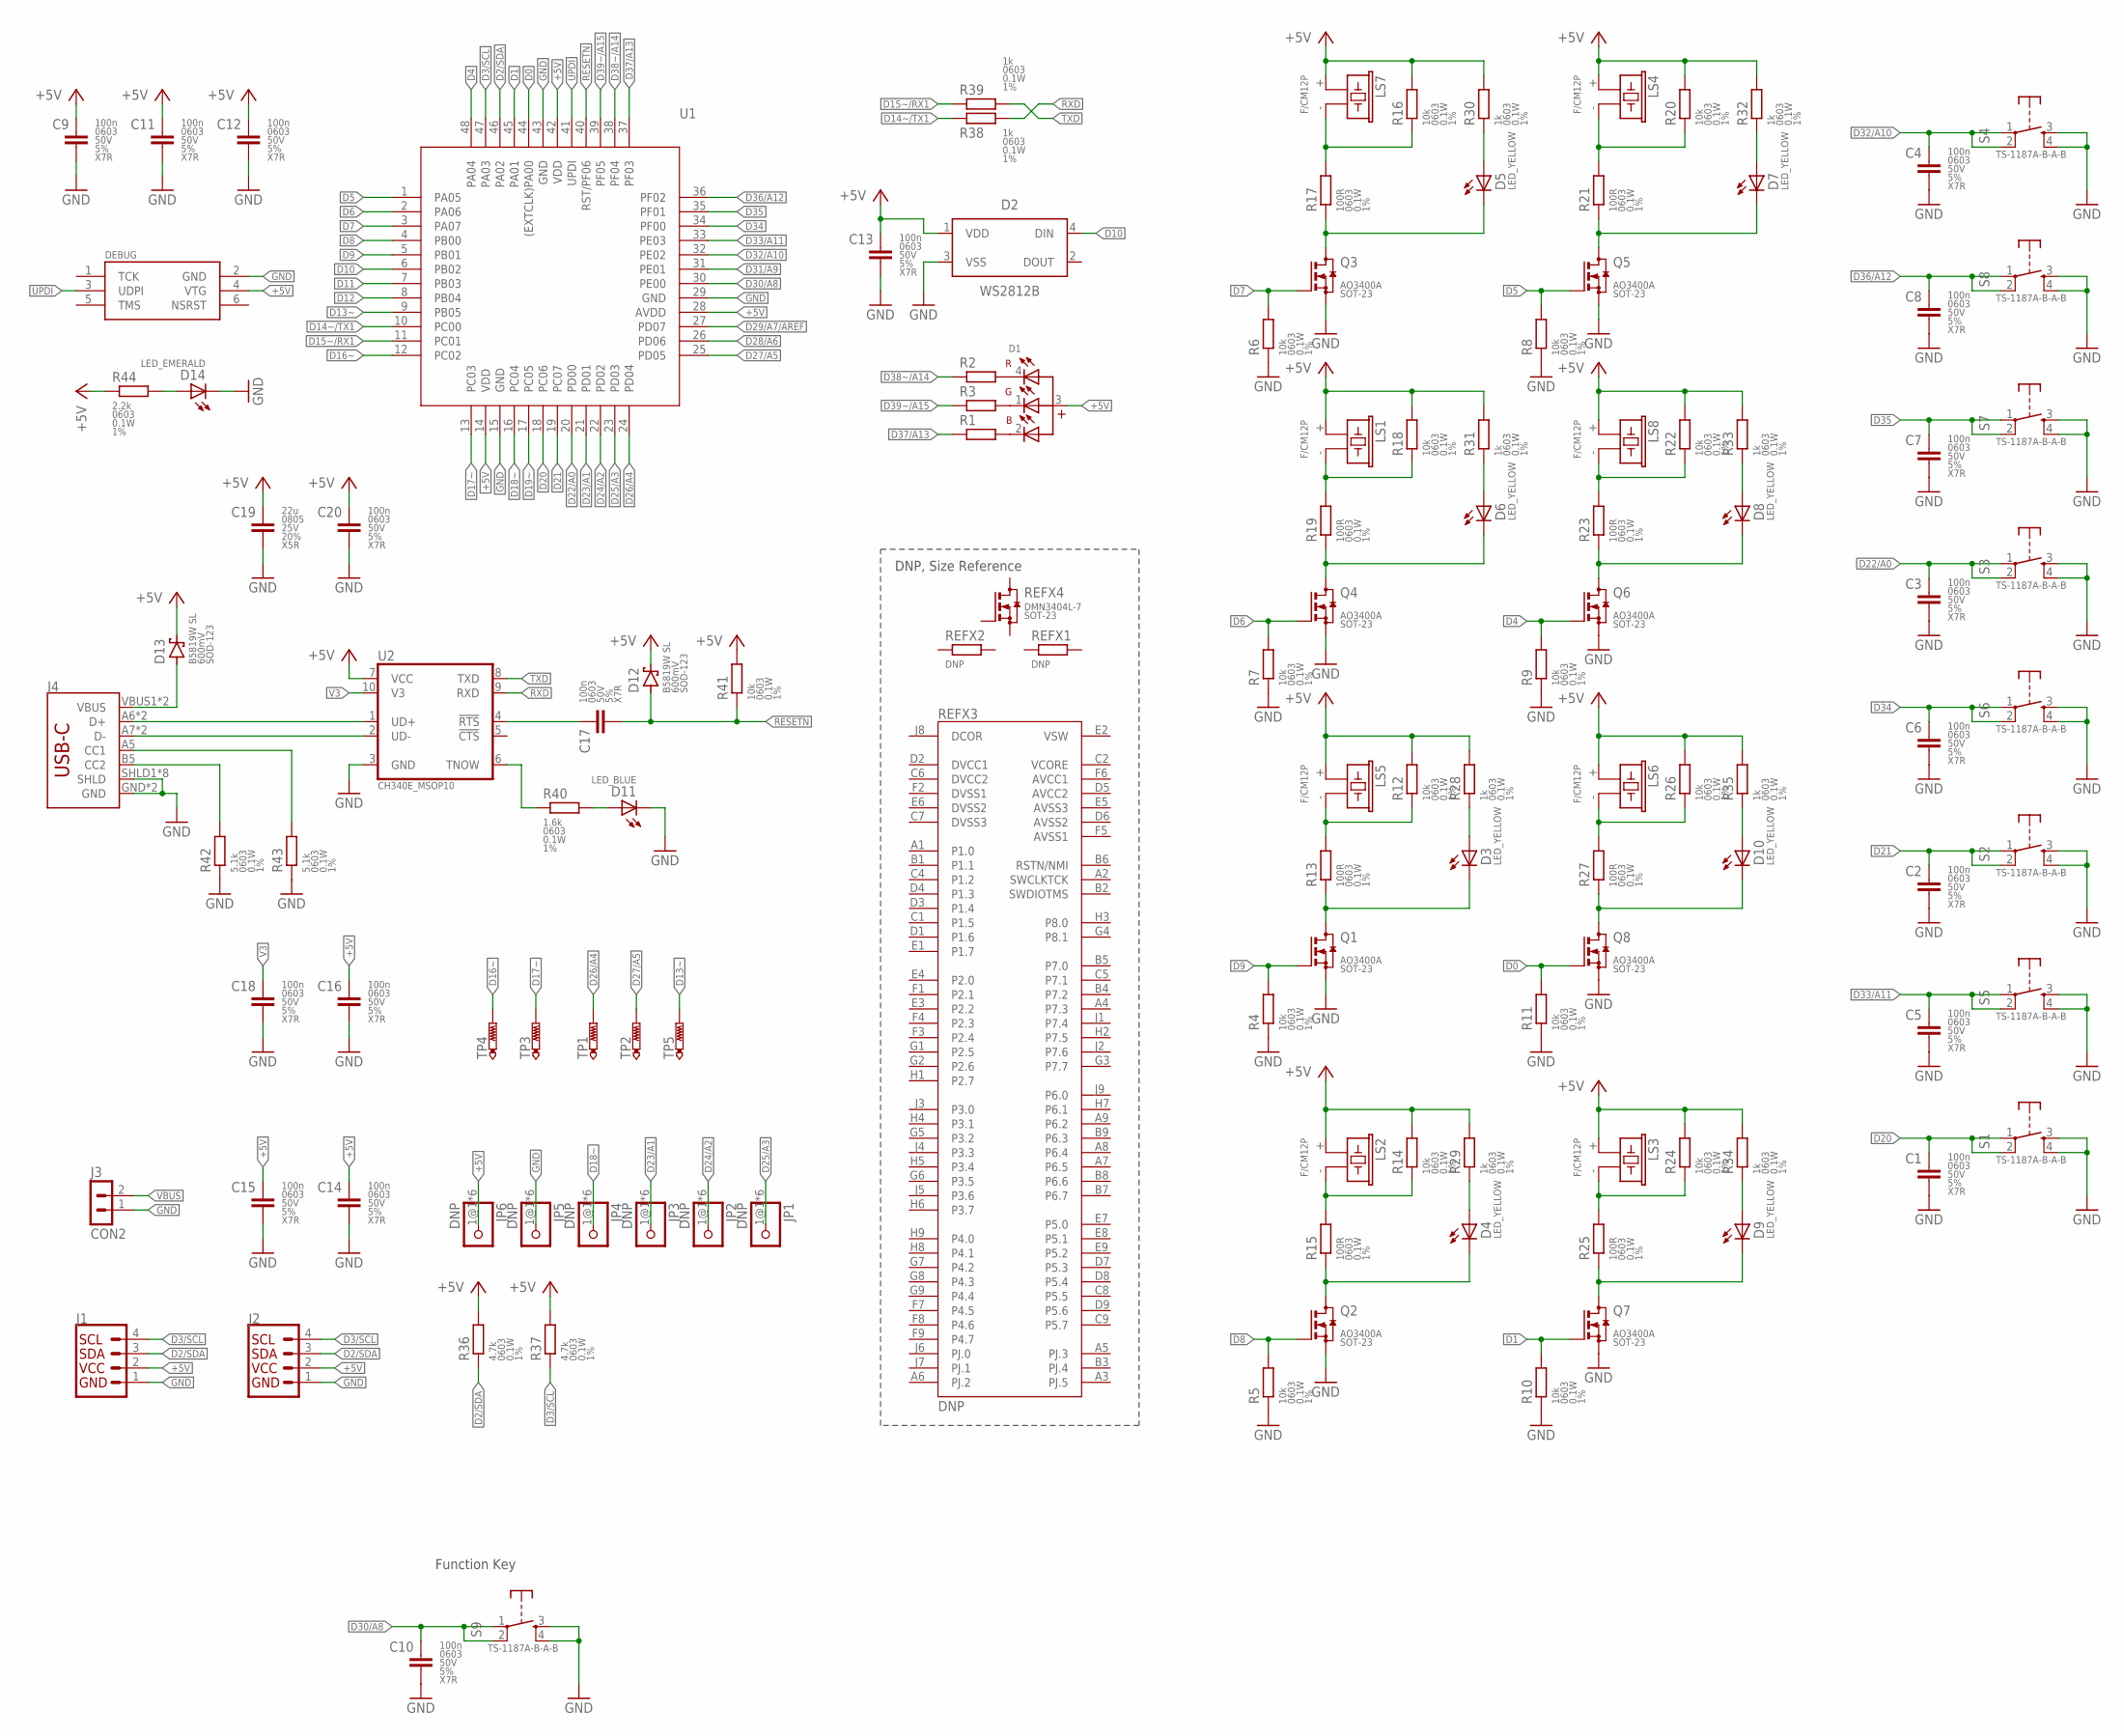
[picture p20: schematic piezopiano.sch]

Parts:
C1, C2, C3, C4, C5, C6, C7, C8, C9, C10, C11, C12, C13, C14, C15, C16, C17, C18, C20: 100n; C0603
C19: 22u; C0805
D1: E6C1209RGBC3UDAM173000; WL-SFCX_1210
D2: WS2812B
D3, D4, D5, D6, D7, D8, D9, D10: LED_YELLOW; LEDC1608X55N_FLAT
D11: LED_BLUE; LEDC1608X55N_FLAT
D12, D13: B5819WSL; SOD123
D14: LED_EMERALD; LEDC1608X55N_FLAT
DEBUG: DNP; 490107670612_DEBUGGING
J1, J2: QWIIC_CONNECTORJS-1MM; 1X04_1MM_RA
J3: CON2; H2-2.54
J4: USB_C2-LAYER; USB-C-16P
JP1, JP2, JP3, JP4, JP5, JP6: DNP; 1X01
LS1, LS2, LS3, LS4, LS5, LS6, LS7, LS8: F/CM12P; CM12P/5.0P
Q1, Q2, Q3, Q4, Q5, Q6, Q7, Q8: AO3400A; SOT23
R1, R40: 1.6k; R0603
R2, R28, R29, R30, R31, R32, R33, R34, R35, R38, R39: 1k; R0603
R3, R44: 2.2k; R0603
R4, R5, R6, R7, R8, R9, R10, R11, R12, R14, R16, R18, R20, R22, R24, R26, R41: 10k; R0603
R13, R15, R17, R19, R21, R23, R25, R27: 100R; R0603
R36, R37: 4.7k; R0603
R42, R43: 5.1k; R0603
REFX1: DNP; R0603
REFX2: DNP; R0805
REFX3: DNP; BGA80
REFX4: DNP; SOT23
S1, S2, S3, S4, S5, S6, S7, S8, S9: TS-1187A-B-A-B; TACTILE_SWITCH_SMD_5.2MM
TP1, TP2, TP3, TP4, TP5: PTR1B1,27; B1,27
U1: ATMEGA4809; TQFP48
U2: CH340E_MSOP10; MSOP10

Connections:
+5V: C9.1, C11.1, C12.1, C13.1, C14.1, C15.1, C16.1, C19.1, C20.1, D1.3 (4), D2.1 (VDD), D12.C, D13.C, DEBUG.4 (VTG), J1.2 (VCC), J2.2 (VCC), JP6.1@1, JP6.1@2, JP6.1@3, JP6.1@4, JP6.1@5, JP6.1@6, LS1.+ (1), LS2.+ (1), LS3.+ (1), LS4.+ (1), LS5.+ (1), LS6.+ (1), LS7.+ (1), LS8.+ (1), R12.2, R14.2, R16.2, R18.2, R20.2, R22.2, R24.2, R26.2, R28.2, R29.2, R30.2, R31.2, R32.2, R33.2, R34.2, R35.2, R36.2, R37.2, R41.2, R44.1, U1.14 (VDD), U1.28 (AVDD), U1.42 (VDD), U2.7 (VCC)
AVCC1: REFX3.F6 (AVCC1)
AVCC2: REFX3.D5 (AVCC2)
AVSS1: REFX3.F5 (AVSS1)
AVSS2: REFX3.D6 (AVSS2)
AVSS3: REFX3.E5 (AVSS3)
D0: Q8.1 (G), R11.2, U1.44 ((EXTCLK)PA00)
D1: Q7.1 (G), R10.2, U1.45 (PA01)
D2/SDA: J1.3 (SDA), J2.3 (SDA), R36.1, U1.46 (PA02)
D3/SCL: J1.4 (SCL), J2.4 (SCL), R37.1, U1.47 (PA03)
D4: Q6.1 (G), R9.2, U1.48 (PA04)
D5: Q5.1 (G), R8.2, U1.1 (PA05)
D6: Q4.1 (G), R7.2, U1.2 (PA06)
D7: Q3.1 (G), R6.2, U1.3 (PA07)
D8: Q2.1 (G), R5.2, U1.4 (PB00)
D9: Q1.1 (G), R4.2, U1.5 (PB01)
D10: D2.4 (DIN), U1.6 (PB02)
D11: U1.7 (PB03)
D12: U1.8 (PB04)
D13~: TP5.TP, U1.9 (PB05)
D14~/TX1: R38.1, U1.10 (PC00)
D15~/RX1: R39.1, U1.11 (PC01)
D16~: TP4.TP, U1.12 (PC02)
D17~: TP3.TP, U1.13 (PC03)
D18~: JP4.1@1, JP4.1@2, JP4.1@3, JP4.1@4, JP4.1@5, JP4.1@6, U1.16 (PC04)
D19~: U1.17 (PC05)
D20: C1.1, S1.1, S1.2, U1.18 (PC06)
D21: C2.1, S2.1, S2.2, U1.19 (PC07)
D22/A0: C3.1, S3.1, S3.2, U1.20 (PD00)
D23/A1: JP3.1@1, JP3.1@2, JP3.1@3, JP3.1@4, JP3.1@5, JP3.1@6, U1.21 (PD01)
D24/A2: JP2.1@1, JP2.1@2, JP2.1@3, JP2.1@4, JP2.1@5, JP2.1@6, U1.22 (PD02)
D25/A3: JP1.1@1, JP1.1@2, JP1.1@3, JP1.1@4, JP1.1@5, JP1.1@6, U1.23 (PD03)
D26/A4: TP1.TP, U1.24 (PD04)
D27/A5: TP2.TP, U1.25 (PD05)
D28/A6: U1.26 (PD06)
D29/A7/AREF: U1.27 (PD07)
D30/A8: C10.1, S9.1, S9.2, U1.30 (PE00)
D31/A9: U1.31 (PE01)
D32/A10: C4.1, S4.1, S4.2, U1.32 (PE02)
D33/A11: C5.1, S5.1, S5.2, U1.33 (PE03)
D34: C6.1, S6.1, S6.2, U1.34 (PF00)
D35: C7.1, S7.1, S7.2, U1.35 (PF01)
D36/A12: C8.1, S8.1, S8.2, U1.36 (PF02)
D37/A13: R1.1, U1.37 (PF03)
D38~/A14: R2.1, U1.38 (PF04)
D39~/A15: R3.1, U1.39 (PF05)
DCOR: REFX3.J8 (DCOR)
DVCC1: REFX3.D2 (DVCC1)
DVCC2: REFX3.C6 (DVCC2)
DVSS1: REFX3.F2 (DVSS1)
DVSS2: REFX3.E6 (DVSS2)
DVSS3: REFX3.C7 (DVSS3)
GND: C1.2, C2.2, C3.2, C4.2, C5.2, C6.2, C7.2, C8.2, C9.2, C10.2, C11.2, C12.2, C13.2, C14.2, C15.2, C16.2, C18.2, C19.2, C20.2, D2.3 (VSS), D11.C, D14.C, DEBUG.2 (GND), J1.1 (GND), J2.1 (GND), J3.1, J4.GND, J4.GND2 (GND), J4.SHLD1 (SHLD), J4.SHLD2 (SHLD), J4.SHLD3 (SHLD), J4.SHLD4 (SHLD), J4.SHLD5 (SHLD), J4.SHLD6 (SHLD), J4.SHLD7 (SHLD), J4.SHLD8 (SHLD), JP5.1@1, JP5.1@2, JP5.1@3, JP5.1@4, JP5.1@5, JP5.1@6, Q1.2 (S), Q2.2 (S), Q3.2 (S), Q4.2 (S), Q5.2 (S), Q6.2 (S), Q7.2 (S), Q8.2 (S), R4.1, R5.1, R6.1, R7.1, R8.1, R9.1, R10.1, R11.1, R42.1, R43.1, S1.3 (S), S1.4 (S), S2.3 (S), S2.4 (S), S3.3 (S), S3.4 (S), S4.3 (S), S4.4 (S), S5.3 (S), S5.4 (S), S6.3 (S), S6.4 (S), S7.3 (S), S7.4 (S), S8.3 (S), S8.4 (S), S9.3 (S), S9.4 (S), U1.15 (GND), U1.29 (GND), U1.43 (GND), U2.3 (GND)
unnamed: C17.1, U2.4 (!RTS)
unnamed: D6.C, Q4.3 (D), R19.1
unnamed: D3.C, Q1.3 (D), R13.1
unnamed: LS2.- (2), R14.1, R15.2
unnamed: D7.C, Q5.3 (D), R21.1
unnamed: LS8.- (2), R22.1, R23.2
unnamed: D10.C, Q8.3 (D), R27.1
unnamed: D14.A, R44.2
unnamed: D5.C, Q3.3 (D), R17.1
unnamed: LS1.- (2), R18.1, R19.2
unnamed: LS5.- (2), R12.1, R13.2
unnamed: D4.C, Q2.3 (D), R15.1
unnamed: LS4.- (2), R20.1, R21.2
unnamed: D8.C, Q6.3 (D), R23.1
unnamed: LS6.- (2), R26.1, R27.2
unnamed: LS3.- (2), R24.1, R25.2
unnamed: D9.C, Q7.3 (D), R25.1
unnamed: LS7.- (2), R16.1, R17.2
unnamed: R40.1, U2.6 (TNOW)
unnamed: D11.A, R40.2
unnamed: D1.4 (R), R2.2
unnamed: D5.A, R30.1
unnamed: D7.A, R32.1
unnamed: D8.A, R33.1
unnamed: D6.A, R31.1
unnamed: D10.A, R35.1
unnamed: D3.A, R28.1
unnamed: D1.2 (B), R1.2
unnamed: J4.B5 (CC2), R42.2
unnamed: J4.A5 (CC1), R43.2
unnamed: J4.A6 (D+), J4.B6 (D+), U2.1 (UD+)
unnamed: J4.A7 (D-), J4.B7 (D-), U2.2 (UD-)
unnamed: D4.A, R29.1
unnamed: D9.A, R34.1
unnamed: D1.1 (G), R3.2
RESETN: C17.2, D12.A, R41.1, U1.40 (RST/PF06)
RXD: R38.2, U2.9 (RXD)
TXD: R39.2, U2.8 (TXD)
UPDI: DEBUG.3 (UDPI), U1.41 (UPDI)
V3: C18.1, U2.10 (V3)
VBUS: D13.A, J3.2, J4.VBUS1 (VBUS), J4.VBUS2 (VBUS)
VCORE: REFX3.C2 (VCORE)
VSW: REFX3.E2 (VSW)

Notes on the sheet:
DNP, Size Reference
Function Key

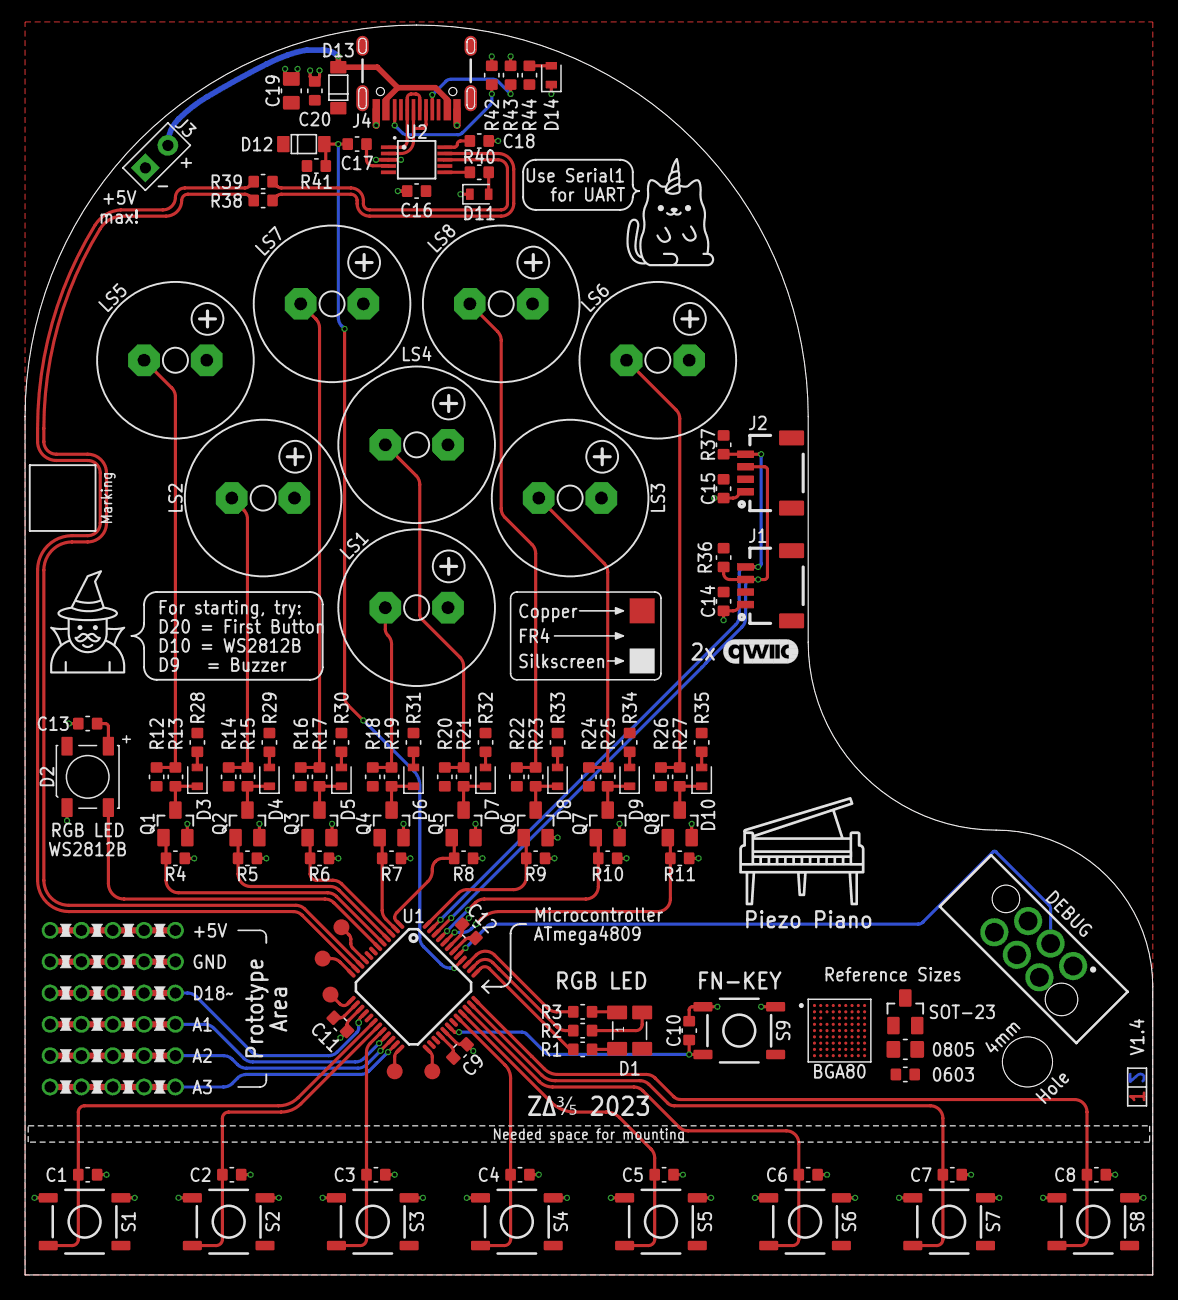
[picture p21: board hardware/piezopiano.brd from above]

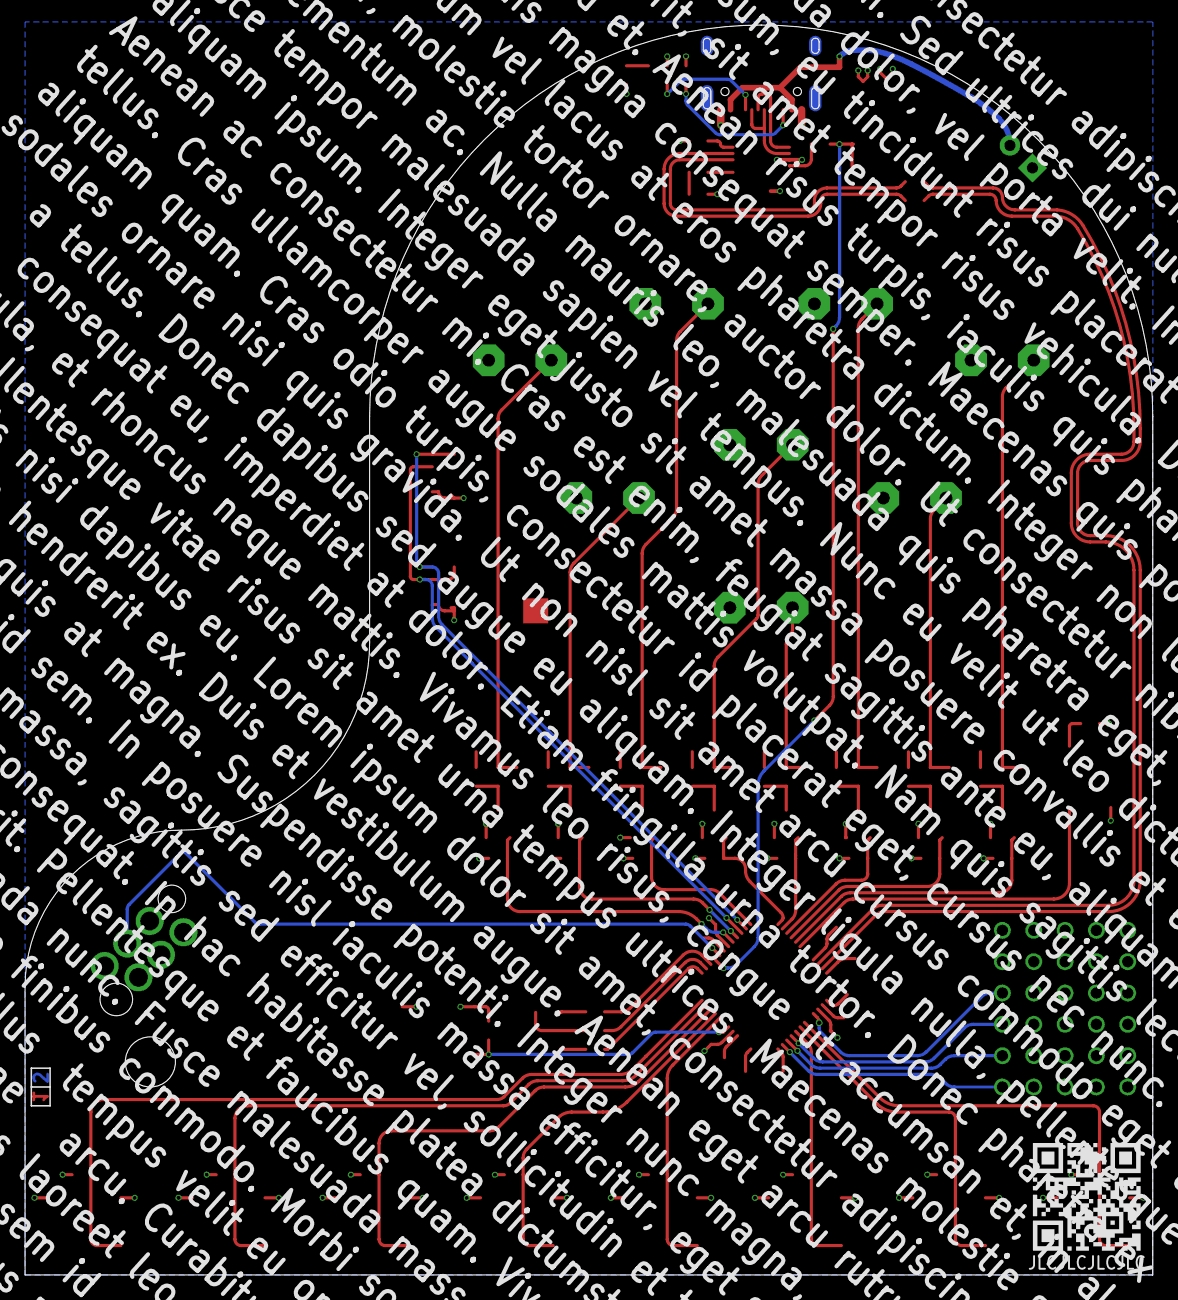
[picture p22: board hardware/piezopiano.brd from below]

Board: 2 copper layers, 90.0 x 99.7 mm, 134 parts (2 on the bottom side), 77 nets.

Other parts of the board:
U$1: STACKUP-2L
U$2: PIANO-10MM
U$3: WIZARD-6MM
U$4: QWIIC_6MM
U$5: EXPLANATION-2-2MM
U$6: QR-SPACE
U$7: CATICORN-7MM
U$100: GITHUB-JRZ-10
U$101: JLC_UID

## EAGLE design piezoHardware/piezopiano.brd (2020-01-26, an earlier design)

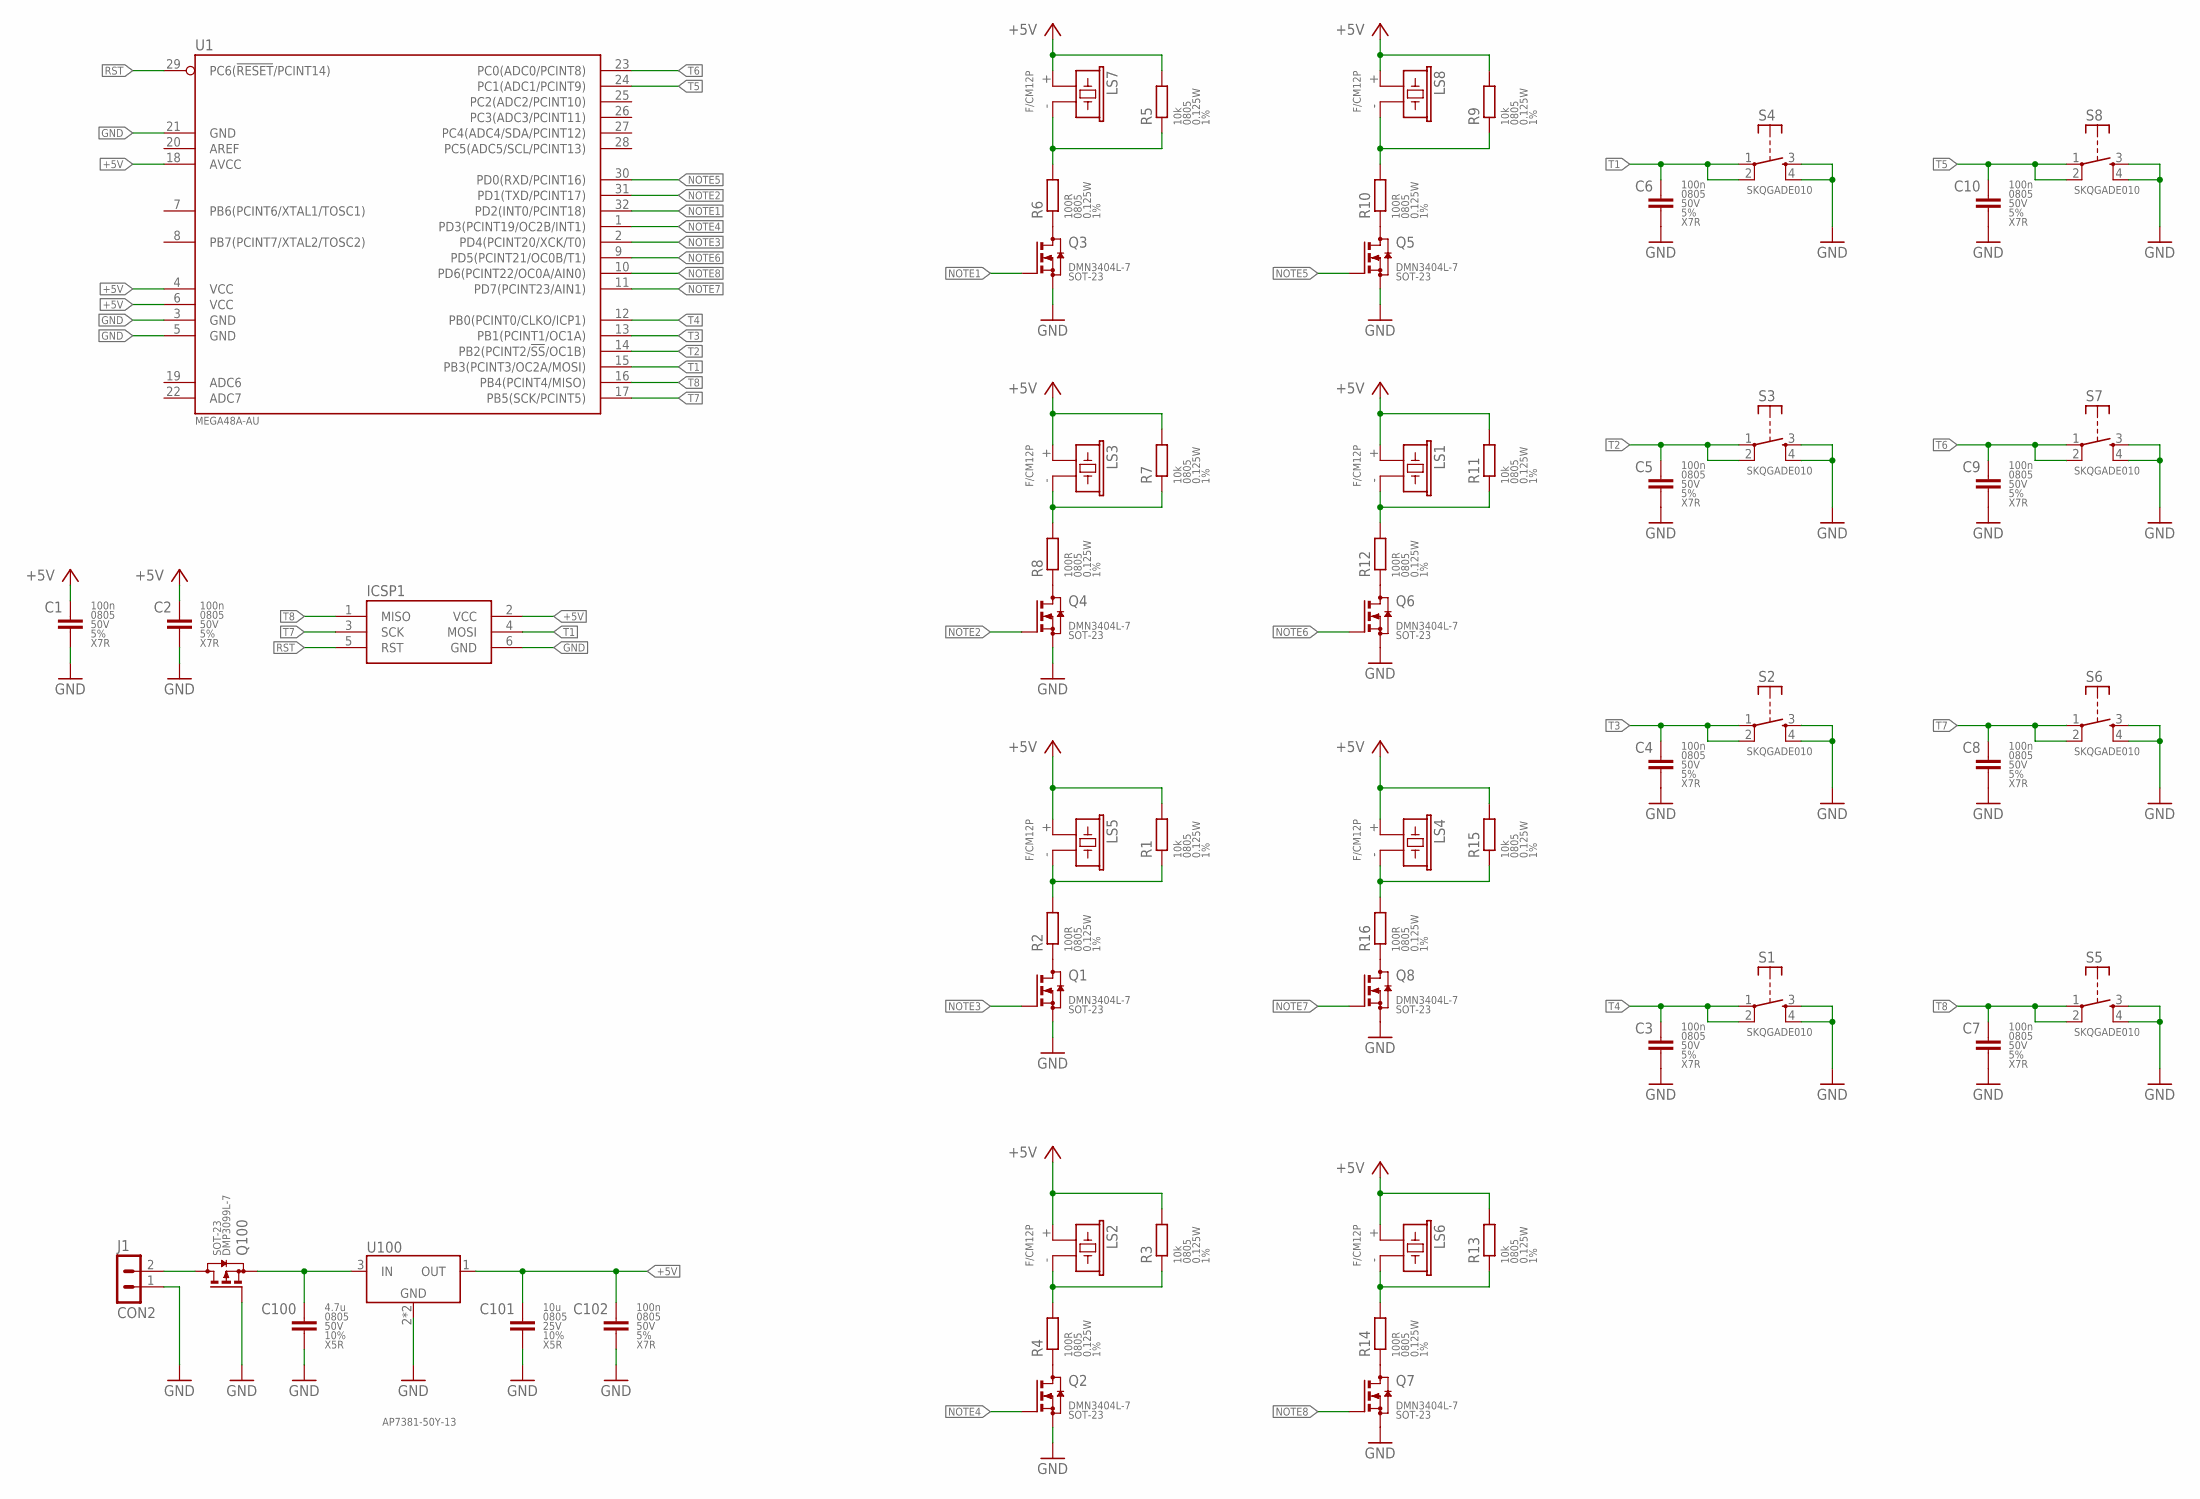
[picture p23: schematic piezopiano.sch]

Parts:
C1, C2, C3, C4, C5, C6, C7, C8, C9, C10, C102: 100n; C0805
C100: 4.7u; C0805
C101: 10u; C0805
ICSP1: AVRISP2.54MM; AVRISP-2.54
J1: CON2; H2-2.54
LS1, LS2, LS3, LS4, LS5, LS6, LS7, LS8: F/CM12P; CM12P/5.0P
Q1, Q2, Q3, Q4, Q5, Q6, Q7, Q8: DMN3404L; SOT23
Q100: DMP3099L; SOT23
R1, R3, R5, R7, R9, R11, R13, R15: 10k; R0805
R2, R4, R6, R8, R10, R12, R14, R16: 100R; R0805
S1, S2, S3, S4, S5, S6, S7, S8: SKQGADE010; TACTILE_SWITCH_SMD_5.2MM
U1: MEGA48A-AU; TQFP32-08
U100: AP7381-50Y-13; SOT89

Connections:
+5V: C1.1, C2.1, C101.1, C102.1, ICSP1.2 (VCC), LS1.+ (1), LS2.+ (1), LS3.+ (1), LS4.+ (1), LS5.+ (1), LS6.+ (1), LS7.+ (1), LS8.+ (1), R1.2, R3.2, R5.2, R7.2, R9.2, R11.2, R13.2, R15.2, U1.4 (VCC), U1.6 (VCC), U1.18 (AVCC), U100.1 (OUT)
GND: C1.2, C2.2, C3.2, C4.2, C5.2, C6.2, C7.2, C8.2, C9.2, C10.2, C100.2, C101.2, C102.2, ICSP1.6 (GND), J1.1, Q1.2 (S), Q2.2 (S), Q3.2 (S), Q4.2 (S), Q5.2 (S), Q6.2 (S), Q7.2 (S), Q8.2 (S), Q100.1 (G), S1.3 (S), S1.4 (S), S2.3 (S), S2.4 (S), S3.3 (S), S3.4 (S), S4.3 (S), S4.4 (S), S5.3 (S), S5.4 (S), S6.3 (S), S6.4 (S), S7.3 (S), S7.4 (S), S8.3 (S), S8.4 (S), U1.3 (GND), U1.5 (GND), U1.21 (GND), U100.2 (GND), U100.2@1 (GND)
unnamed: J1.2, Q100.3 (D)
unnamed: Q4.3 (D), R8.1
unnamed: Q1.3 (D), R2.1
unnamed: LS2.- (2), R3.1, R4.2
unnamed: Q5.3 (D), R10.1
unnamed: LS1.- (2), R11.1, R12.2
unnamed: Q8.3 (D), R16.1
unnamed: Q7.3 (D), R14.1
unnamed: Q3.3 (D), R6.1
unnamed: LS3.- (2), R7.1, R8.2
unnamed: LS5.- (2), R1.1, R2.2
unnamed: Q2.3 (D), R4.1
unnamed: LS8.- (2), R9.1, R10.2
unnamed: Q6.3 (D), R12.1
unnamed: LS4.- (2), R15.1, R16.2
unnamed: LS6.- (2), R13.1, R14.2
unnamed: C100.1, Q100.2 (S), U100.3 (IN)
unnamed: LS7.- (2), R5.1, R6.2
NOTE1: Q3.1 (G), U1.32 (PD2(INT0/PCINT18))
NOTE2: Q4.1 (G), U1.31 (PD1(TXD/PCINT17))
NOTE3: Q1.1 (G), U1.2 (PD4(PCINT20/XCK/T0))
NOTE4: Q2.1 (G), U1.1 (PD3(PCINT19/OC2B/INT1))
NOTE5: Q5.1 (G), U1.30 (PD0(RXD/PCINT16))
NOTE6: Q6.1 (G), U1.9 (PD5(PCINT21/OC0B/T1))
NOTE7: Q8.1 (G), U1.11 (PD7(PCINT23/AIN1))
NOTE8: Q7.1 (G), U1.10 (PD6(PCINT22/OC0A/AIN0))
RST: ICSP1.5 (RST), U1.29 (PC6(!RESET!/PCINT14))
T1: C6.1, ICSP1.4 (MOSI), S4.1, S4.2, U1.15 (PB3(PCINT3/OC2A/MOSI))
T2: C5.1, S3.1, S3.2, U1.14 (PB2(PCINT2/!SS!/OC1B))
T3: C4.1, S2.1, S2.2, U1.13 (PB1(PCINT1/OC1A))
T4: C3.1, S1.1, S1.2, U1.12 (PB0(PCINT0/CLKO/ICP1))
T5: C10.1, S8.1, S8.2, U1.24 (PC1(ADC1/PCINT9))
T6: C9.1, S7.1, S7.2, U1.23 (PC0(ADC0/PCINT8))
T7: C8.1, ICSP1.3 (SCK), S6.1, S6.2, U1.17 (PB5(SCK/PCINT5))
T8: C7.1, ICSP1.1 (MISO), S5.1, S5.2, U1.16 (PB4(PCINT4/MISO))

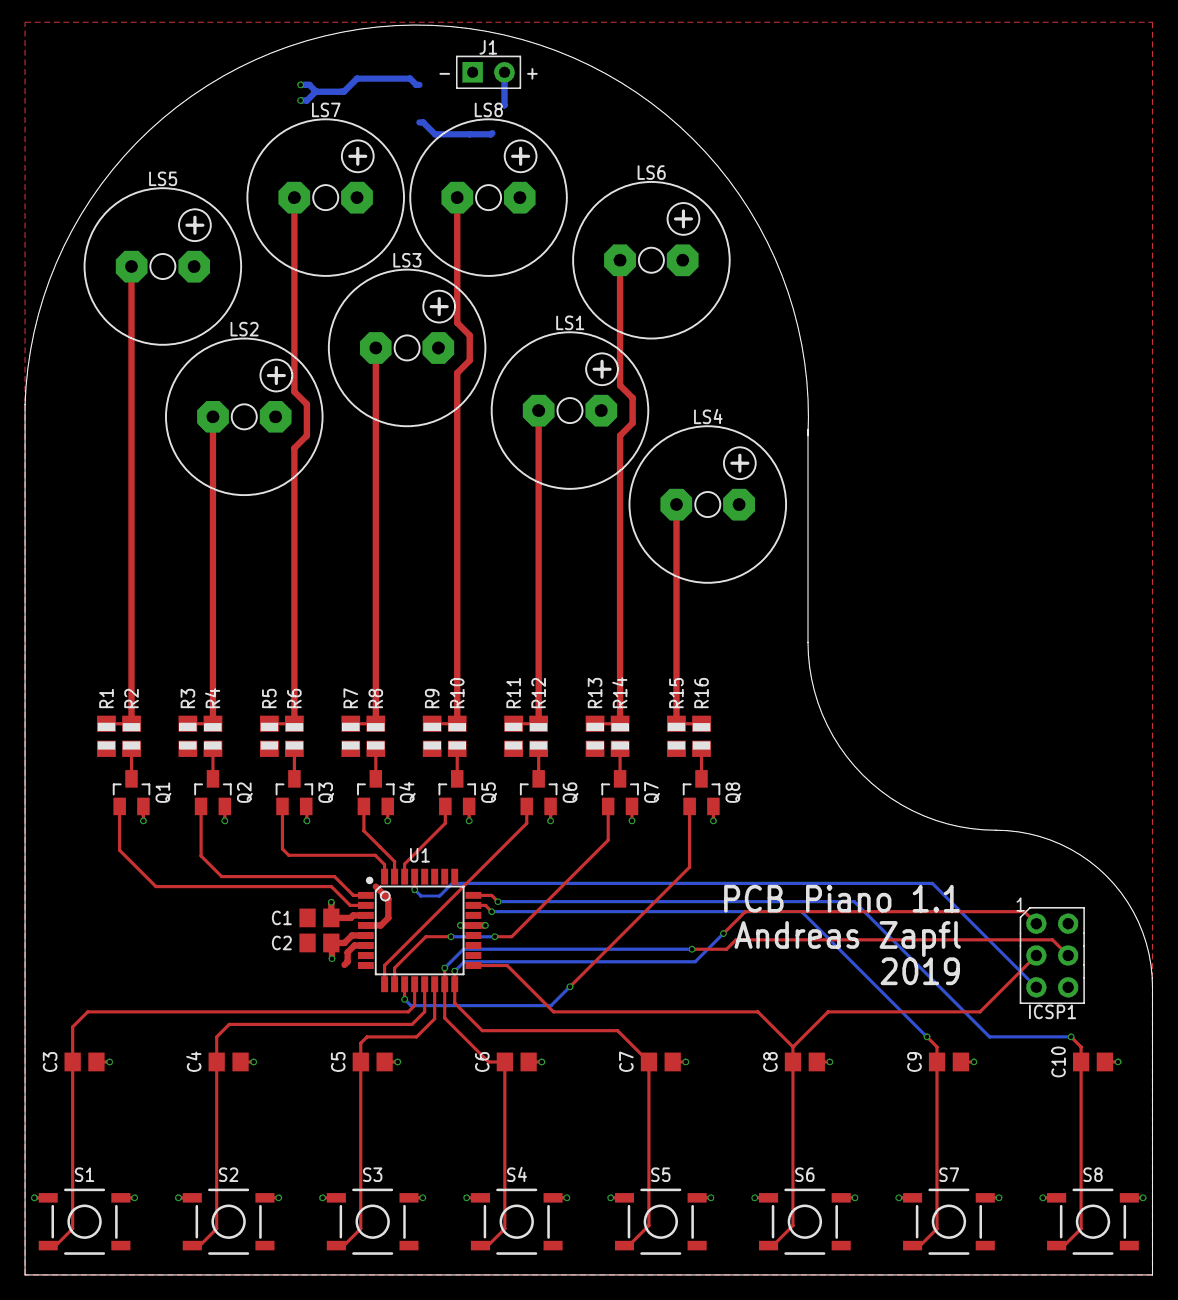
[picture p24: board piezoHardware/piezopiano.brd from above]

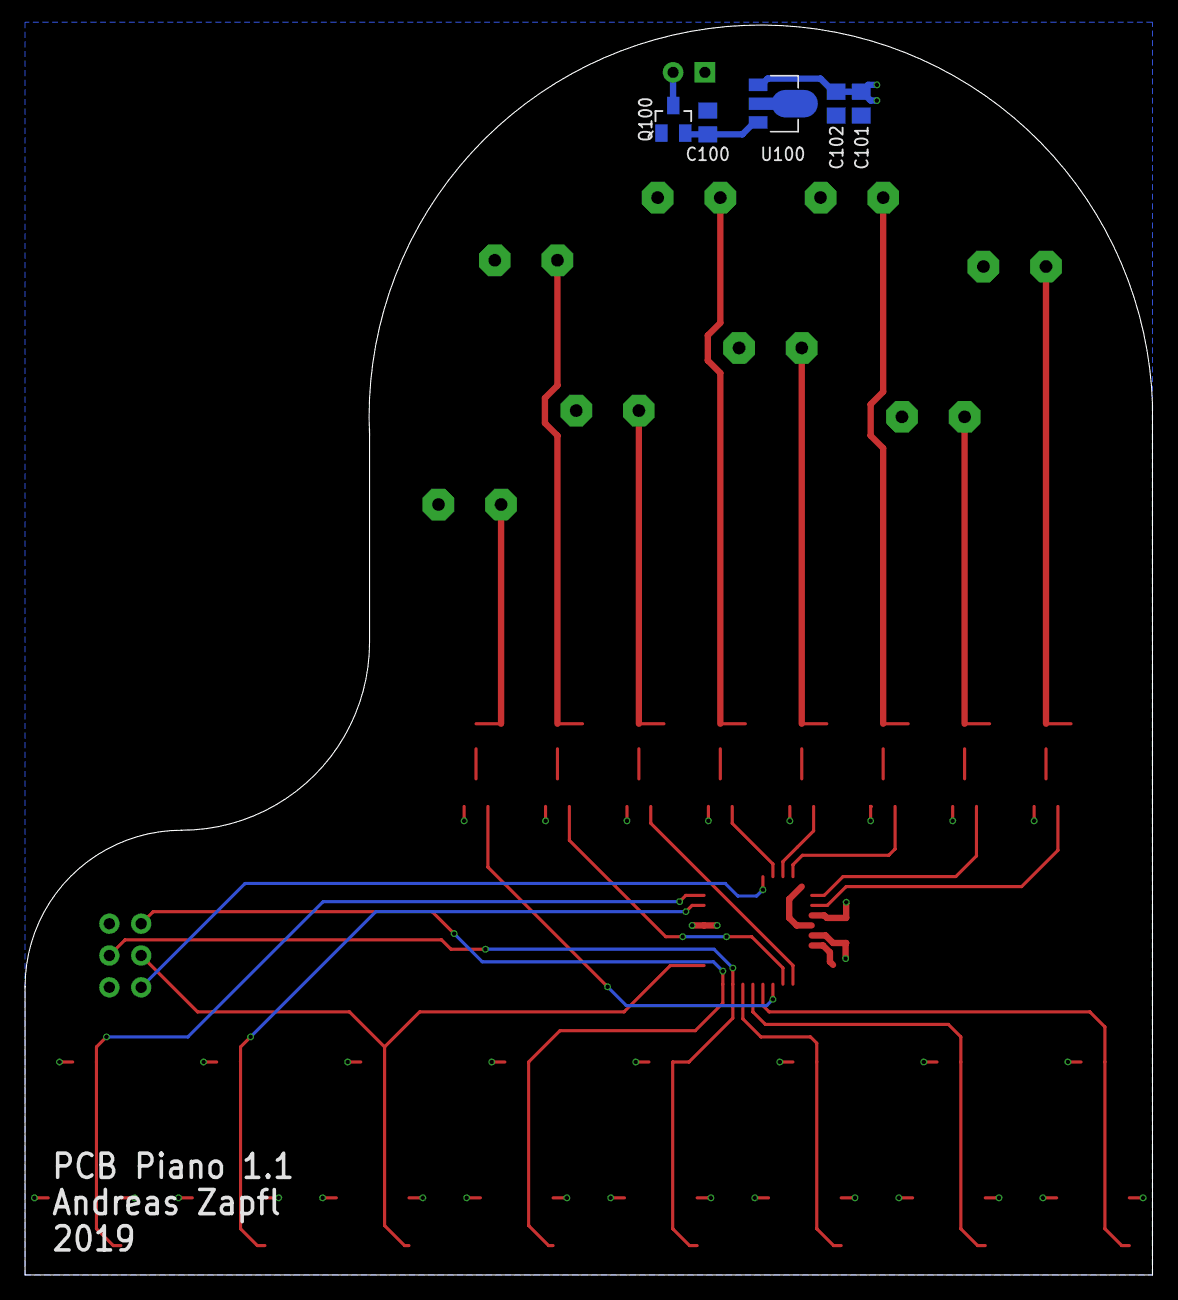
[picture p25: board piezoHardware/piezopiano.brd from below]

Board: 2 copper layers, 90.0 x 99.8 mm, 58 parts (5 on the bottom side), 37 nets.

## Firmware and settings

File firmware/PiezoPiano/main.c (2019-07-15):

/****************************** FH Joanneum ECE16 ******************************

Exercise: 			Piezo Piano
Date:				2019-07-02
Type:				Main Source File

Missing:			Sleepmodes

****************************** Andreas Zapfl ******************************/

// ********************************************* INCLUDES ***************
#include "hal_general.h"

// ********************************************* DEFINES ***************

// ********************************************* SERIAL NUMBER ***************

// ********************************************* GLOBAL VAR ***************

// ********************************************* MAIN FUNCTION **************
int main(void)
{
	HAL_Init();		// Hardware Peripheral Init
	
	sei();			// Global Enable Interrupts
	
	while(1){}
}

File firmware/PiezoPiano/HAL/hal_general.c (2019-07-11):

/****************************** FH Joanneum ECE16 ******************************

Exercise: 			Piezo Piano
Date:				2019-07-02
Type:				HAL GENERAL

****************************** Andreas Zapfl ******************************/

// ********************************************* INCLUDES ***************
#include "hal_general.h"

// ********************************************* GLOBAL VARIABLES ***************


// ********************************************* OTHER FUNCTIONS ***************
void HAL_Init()
{
	HAL_CLKCTRL_Init();				// System Clock Init
	HAL_GPIO_Init();				// GPIO Init
	HAL_TimerC0_Init();				// TimerA1 Init
}

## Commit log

2019-07-11 Initial Commit Working PCB and Code
    Missing downgrade microcontroller and power supply fix
    [piezopiano.brd, piezopiano.sch]
2019-07-11 LDO added
    [piezopiano.brd, piezopiano.sch]
2019-07-15 Frequency correction for note generation
    [main.c]
2019-07-15 ATmega silkscreen change
    [piezopiano.brd, piezopiano.sch]
2019-07-16 Partly finished layout
    Missing crystal
    [piezopiano.brd, piezopiano.sch]
2020-01-26 Minor part update
    [piezopiano.brd, piezopiano.sch]
2020-04-23 Restructured folders and added rednders of pcb
    [piezopiano.brd, piezopiano.sch]
2020-07-07 Improved 3D piezo model
    [piezopiano.brd, piezopiano.sch]
2020-08-07 Added USB C and UART
    [piezopiano.brd, piezopiano.sch]
2020-08-07 Added Battery Connector
    [piezopiano.brd, piezopiano.sch]
2020-10-01 Added Battery Management IC
    [piezopiano.brd, piezopiano.sch]
2021-02-07 Changed to 328 for Arduino support
    Changed to ATmega328
    Fixed radius from outline
    Corrected CH340E
    Changed Pinout 328
    [piezopiano.brd, piezopiano.sch]
2021-02-07 Test cutout battery connector
    [piezopiano.brd]
2021-02-07 Added RGB LED
    [piezopiano.brd, piezopiano.sch]
2021-02-10 Added inductor, corrected LED
    [piezopiano.brd, piezopiano.sch]
2021-02-24 Added housing information and shifted piezo to be symmetric
    [piezopiano.brd]
2021-02-24 Mirrored piezos
    [piezopiano.brd]
2021-06-08 Added roundness to footprints
    [piezopiano.brd, piezopiano.sch]
2021-06-08 Changed ICSP
    [piezopiano.brd, piezopiano.sch]
2021-06-08 Changed pin naming at atmega328
    [piezopiano.brd, piezopiano.sch]
2021-09-13 Changed to 4809
    [piezopiano.brd, piezopiano.sch]
2021-09-17 Added proto area
    [piezopiano.brd, piezopiano.sch]
2021-09-20 Placement changes
    [piezopiano.brd, piezopiano.sch]
2021-09-26 Minor routing updates
    [piezopiano.brd]
2021-09-26 Created different branch for battery support, deleted battery parts
    [piezopiano.brd, piezopiano.sch]
2021-09-26 Added QWIIC connector
    [piezopiano.brd, piezopiano.sch]
2021-09-26 Mounting info added
    [piezopiano.brd]
2021-09-26 Deleted not needed wire
    [piezopiano.brd]
2021-09-26 Added round wires
    [piezopiano.brd]
2021-09-27 Routing and Placement changes
    [piezopiano.brd, piezopiano.sch]
2021-09-30 Added PCB artwork
    [piezopiano.brd, piezopiano.sch]
2021-09-30 Added parts for size reference
    [piezopiano.brd, piezopiano.sch]
2021-10-01 Schematic cleanup
    [piezopiano.brd, piezopiano.sch]
2021-10-01 Text for bottom added
    [piezopiano.brd]
2021-10-01 Fixed bottom artwork
    [piezopiano.brd]
2021-10-01 Updated artwork
    [piezopiano.brd]
2021-10-03 Changed artwork to own design
    [piezopiano.brd]
2021-10-03 Updated 3D files
    [piezopiano.brd, piezopiano.sch]
2021-10-03 Added 3D step files for connector
    [piezopiano.brd]
2021-10-03 Rounded traces
    [piezopiano.brd, piezopiano.sch]
2021-10-03 Wizard speaks
    [piezopiano.brd, piezopiano.sch]
2021-10-10 Routing first draft finished
    [piezopiano.brd, piezopiano.sch]
2021-10-10 Added layer explenation
    [piezopiano.brd, piezopiano.sch]
2021-10-10 Changed silkscreen
    [piezopiano.brd]
2021-10-12 Updated drills
    [piezopiano.brd]
2021-10-15 Renumbered, Gerbers Created
    [PiezoPiano_BOM_20211015_1241.xlsx, piezopiano.brd, piezopiano.csv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]
2021-10-20 Added 3d cad files
    [2019.07.02 21.37 - PiezoPiano.FCStd, pp_20200707.step, pp_cutout_20211020.step]
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2021-10-23 Added qwiic logo
    [piezopiano.brd]
2021-10-23 Updated silkscreen, created Gerber
    [piezopiano.brd, piezopiano.sch]
2021-10-23 Updated font size in description
    [piezopiano.brd]
2021-10-23 Added images and updated device data
    [PiezoPiano_BOM_20211015_1241.xlsx, PiezoPiano_BOM_20211023_1024.xlsx, piezopiano.brd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]
2021-10-23 Changed silk, generated Gerber, updated bom
    [piezopiano.brd, piezopiano_jlc_bom_20211023.xlsx, piezopiano_jlc_pnp_20211023.xlsx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]
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2021-10-24 Reverted to local libraries
    [piezopiano.brd, piezopiano.sch]
2021-10-24 Cleanup renders
    [pp_cutouts_20211024.step]
2021-10-24 Added bom infos
    [PiezoPiano_BOM_20211023_1024.xlsx]
2021-10-24 Added csv bom
    [piezopiano_bom_full_20211024.csv]
2021-10-24 added mf files
    [piezopiano_eecart_bom_20211023.xlsx]
2021-11-12 Fixed silkscreen errors
    [piezopiano.brd]
2021-12-29 Added UART RST
    [piezopiano.brd, piezopiano.sch]
2022-01-06 Routed RST
    [piezopiano.brd]
2022-01-06 Added diode, renamed pins to pinout
    [piezopiano.brd, piezopiano.sch]
2022-01-09 Pinout change piezos, silkscreen edit
    [piezopiano.brd, piezopiano.sch]
2022-01-09 Added caps for I2C
    [piezopiano.brd, piezopiano.sch]
2022-01-11 WS2812 pinout bugfix
    [piezopiano.brd, piezopiano.sch]
2022-01-22 Prototype area adapted
    [piezopiano.brd, piezopiano.sch]
2022-01-22 Fixed proto area
    [piezopiano.brd, piezopiano.sch]
2022-01-22 Added 2 TP
    [piezopiano.brd, piezopiano.sch]
2022-01-22 Increased hole size to 4mm
    [piezopiano.brd, piezopiano.sch]
2022-01-25 Added pulldown resistors
    [piezopiano.brd, piezopiano.sch]
2022-01-25 Minor fix, created gerbers and data
    [PiezoPiano_BOM_20211023_1024.xlsx, PiezoPiano_v13_BOM_20220125_2147.xlsx, piezopiano.brd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]
2022-02-05 Updated 3D models
    [piezopiano.brd, piezopiano.sch]
2022-02-05 Updated Soldermask Color and added pictures
    [piezopiano.brd]
2022-02-28 Fixed 10k resistor
    [piezopiano_v13_jlc_bom_20220125.xlsx]
2022-02-28 Fixed WS2812 LED
    [piezopiano.brd, piezopiano.sch]
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2022-03-03 Updated CAD
    [pp_basis_20220303.step]
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2022-03-03 Bugfix size and name
    [PiezoPiano_v13_BOM_20220125_2147.xlsx]
2022-03-03 Fixed QWIIC print
2022-04-06 Fixed LED bug and tuned sound
    [piezopiano_test.ino]
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2022-12-18 Working on new version, added pullups for i2c
    [piezopiano.brd, piezopiano.sch]
2022-12-18 Added fn key
    [piezopiano.brd, piezopiano.sch]
2022-12-18 Added testpoints
    [piezopiano.brd, piezopiano.sch]
2022-12-18 Adapted CAD
    [pp_abdeckung_20220407.step, pp_bein_20220407.step, pp_vorderplatte_20220407.step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]
2022-12-18 Silkscreen change
    [piezopiano.brd]
2022-12-18 Changed ws2812 silkscreen, routed power in
    [piezopiano.brd, piezopiano.sch]
2022-12-18 Added correct revision number
    [piezopiano.brd, piezopiano.sch]
2022-12-19 Rework folder structure
    [piezopiano.brd, piezopiano_v13_jlc_bom_20220125.xlsx, piezopiano_v13_jlc_pnp_20220125.xlsx]
2022-12-28 Added LCSC MPNs
    [piezopiano.brd, piezopiano.sch]
2022-12-28 Changed RGB MPN
    [piezopiano.brd, piezopiano.sch]
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2023-02-17 CAD rework
    [pp-pcb-basis-20230125.dxf, pp_basis_20230125.FCStd]
2023-02-17 Minor fixes and data generation
    [PP_V14_BOM_20230217_2015.xlsx, PiezoPiano_v13_BOM_20220125_2147.xlsx, piezopiano.brd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]
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
